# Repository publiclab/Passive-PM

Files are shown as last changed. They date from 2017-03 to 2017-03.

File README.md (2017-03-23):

## Introduction to the Passive PM Monitor
A [passive PM monitor](https://publiclab.org/wiki/passive-pm) collects airborne particles deposited on its surface without the use of mechanical or electrical systems. 

This passive PM monitor collects particulate matter on a glass slide cover. The slide cover is then [imaged with a microscope](microscopy/README.md), each particle is measured, and an [analysis protocol](analysis) is used to extrapolate the airborne concentration of coarse PM (PM<sub>2.5-10</sub>) during the sample period. 

The Passive PM Monitor was developed at the University of Iowa based on the University of North Carolina Passive PM Monitor. Components developed at UNC are subject to US Patent 6,321,608 until April 7, 2020 and are not to be used unless under [license](license.md). Public Lab has an evaluation license from UNC for evaluating the use of the monitor for community science monitoring. [Contact Public Lab](staff@publiclab.org) about becoming an evaluation partner. 
 
## Components of the Passive PM Monitor

### Hardware
The core Passive PM Monitor hardware is an aluminum [SEM stub](SEM_stub) and machined aluminum cap and screen, underneath which sits a microscope slide cover. This component is subject to patent protection.

[image]

The SEM stub sits between a [housing](housing) consisting of two plates that protect the slide from inclement weather and also normalize the flow of air across the stub and enable the use of the Passive PM Monitor in outdoor environments.

[image]

### [Microscopy](microscopy)
Accurate measurements of PM<sub>2.5-10</sub> require that the slide surface where particles are deposited be imaged as completely as possible.  It is recommended to automate this process. We are using the [OpenFlexure]x(LINK) microscope for automated imaging.

Images must then be processed to isolate and measure each deposited particle. Processing is currently happening with ImageJ.  See more details in [Microscopy](microscopy)

[4-up image of processing]

### Analysis
Imaged and sized particles are entered into an analysis protocol that uses an atmospheric physics model to determine airborne concentration of coarse particulates (PM<sub>2.5-10</sub>) during the sample period.  This equation was developed at UNC and is subject to patent protections. 

### [how you can contribute](contributing.md)

### [Bibliography](Bibliography.md)

### About this project
The TALA repository is a project of [Public Lab](www.publiclab.org) to [collect ongoing research into kite anemometry](www.publiclab.org/tag/kite-anemometer) into a stable device replicating the TALA and licensed under [CERN OHL 1.2](LiCENSE.md).

To read more about using kite anemometers and find resources and sources used in this repository, visit the [Public Lab Wiki](publiclab.org/wiki/kite-anemometers). To learn more about contibuting, please read our [contribution guidelines](contributing.md).

>Manufacture, use, or sale of this device is protected by U.S. patent 6,321,608, owned by The University of North Carolina at Chapel Hill. Any party desiring a license to use the aforementioned patent for commercial purposes shall contact the Office of Commercialization & Economic Development at UNC at 919-966-3929.

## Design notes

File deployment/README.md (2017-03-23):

##Deploying Passive PM Monitors

https://publiclab.org/notes/mathew/10-26-2015/deploying-passive-particle-monitors

https://publiclab.org/notes/mathew/12-22-2015/passive-particle-monitor-deployments-feedback

_Materials needed_

* [Prepared](../preparation) [Passive PM Monitors](../monitor)
* [Monitor Housing](../housing)
* Tape tabs for covering the monitors (Arrow Flags, 3M)
* Two-axis Bubble Level
* [Deployment Worksheet](deployment.md)

Prepared passive PM monitors are packed in a stack of styrofoam cups, each one covered with a cup.  Each covering cup has a place to write the date and time of deployment. Inside each cup pair is a sampler covered with a tape tab to prevent dust from entering the clean stub in transit.

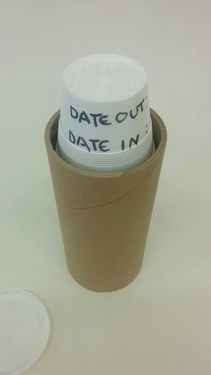
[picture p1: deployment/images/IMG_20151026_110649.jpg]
Boxed up samples


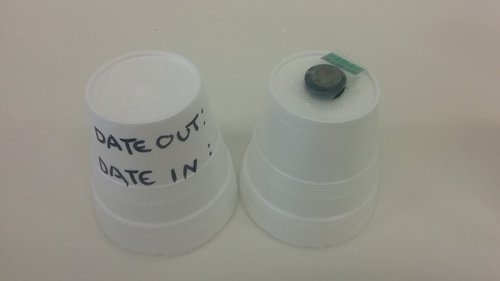
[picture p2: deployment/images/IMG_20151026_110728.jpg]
samples unstacked


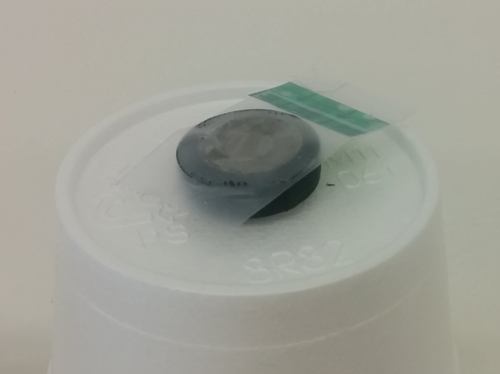
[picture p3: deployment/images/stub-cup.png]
stub close up


In order to analyze the results of a passive PM monitor deployment, each sample requires additional information, which should be recorded on separate Deployment Worksheet.

##Pick a Location for the housing

Ideally, monitors will be placed 180cm (71") above the ground, and a distance from obstacles greater than the height of those obstacles. Such an ideal deployment is not always possible. Describe and record the location and descriptions of obstacles in the Deployment Worksheet.  If possible, take photos of the deployment site. 

##One Week Deployment

Pick a day and time to deploy the passive PM monitor that you will also be available for in seven days to recover the monitor.  Record the date and time on the Deployment Worksheet.

1.
Clamp the passive PM monitor housing to a pole or other solid object.

2.
 Set the housing level using a bubble level, tightening the ball head's thumb screw.

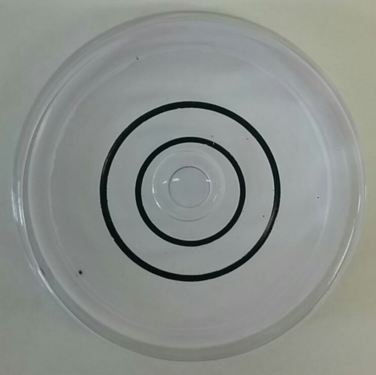
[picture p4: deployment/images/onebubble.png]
double bubble level
 
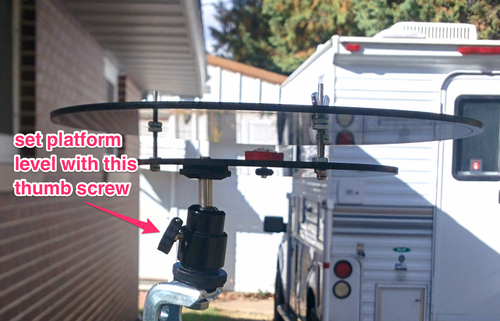
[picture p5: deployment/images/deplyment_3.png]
level the plates
 

3.
Remove sampler stub from box, leaving the tape tab cover on. write down the date and time it was removed on the cover cup.

4.
Unscrew the thumb screws holding the housing's lid on. watch for the rubber washers underneath, they're tiny and easy to lose (we provided some extras - you can use a dish as a catcher).

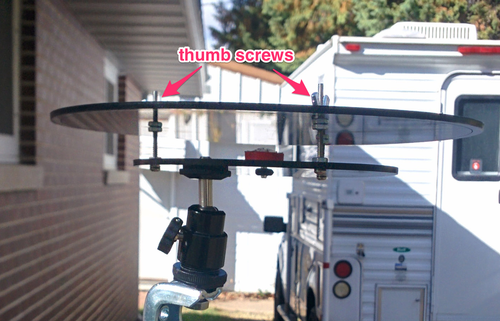
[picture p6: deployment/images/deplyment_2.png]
removing the housing lid


5.
Holding the sampler stub by its sides and supporting the housing with your other hand, press the sampler into the rubber grommet in the center of the housing. Try to avoid touching the top of the monitor, as in the center of the top there is a 1/4" area of fragile mesh that is easy to deform.

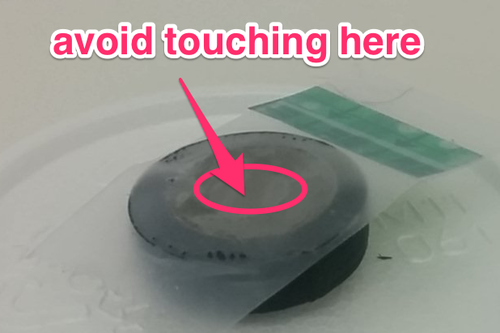
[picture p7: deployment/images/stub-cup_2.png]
Don't touch the fragile mesh


6.
Remove the sticky tab protecting the passive PM monitor and screw the housing's lid back on. The housing lid has a small groove on its underside that catches raindrops, make sure this groove is facing down.

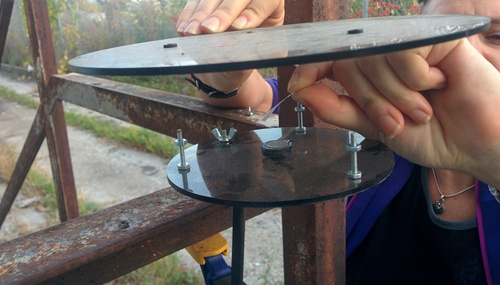
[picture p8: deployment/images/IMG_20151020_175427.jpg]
Re attach the housing's lid


7.
Use the bubble level to check if the housing is level. Reset the level of the housing using the thumb screw on the ball head if necessary.

level the plates

8.
Leave in place for seven days, and record daily weather information on the Deployment Worksheet. 

##Recovery

9.
Check the housing to see that it is still level.  Note any change in the Deployment Worksheet.

10.
Unscrew the housing lid and place a sticky tab over the sampler stub. Replace with a new sampler stub.

11.
Place the exposed sampler stub back in its box and write down the date and time it is returned on its cover cup.

12.
write the time of return on the Deployment Worksheet.

13.
Prepare samples for [microscopy](../microscopy) or package and ship to whomever is conducting the microscopy.

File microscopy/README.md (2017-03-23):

#PM Microscopy
The goal of PM microscopy is to use a visible light microscope and digital camera to capture and measure deposited particles so that their size, shape, and frequency can be [analyzed](../analysis). to extrapolate airborne PM during the sample period. 

The current microscopy hardware and software in use falls short in the face of several imaging issues and could use help. 

##Goals and Confounding Factors

The primary goal is to image and measure as much as possible of surface of the [passive PM monitor's](../monitor) deposition substrate- a glass slide cover- without taking repeat measurements. The greater the area imaged, the more accurate the [analysis](../analysis) gets.  250-300 particles are needed for "analytical certainty," and in the literature, imaging itself contributed 5% to the overall error.  (166, Ott et al. 2008)

The factors to be measured are:

* scale of microscope images in pixels/μm<sup>2</sup>
* area of each particle
 
* perimeter of each particle

From these measurements, additional factors are derived:

* total area imaged
* circularity of each particle (4π x Area/Perimeter<sup>2</sup>)

A microscopy protocol must account for false positives, mis-measurements and other issues arising from the qualities of the particles measured:

* refraction of light by particles
* varying albedo and opacity across each individual particle
* varying albedo and opacity of different types of particles

A microscopy protocol must also account for issues arising from imperfections in the microscope, related equipment, and imagine process including:

* dust and artifacts in the microscope's optics
* dust outside the focal plane
* pixel noise from the image sensor
* variable lighting within each image
* variable lighting between images
* variable lighting and exposure between image/sample sets
* duplicate images of the same particle

Solutions to these issues could be conducted in software or hardware-- a flatter, better focused light source could solve imaging variability, or a flat field or pseudo-flat field correction could solve the issue. 

##Current microscopy imaging protocol

The current protocol is based on manual microscopy using an OpenFlexure microscope.  As automated motor control for the [OpenFlexure](http://www.waterscope.org/3d-printing/) microscope advances, imaging will be [automated](https://github.com/fr293/motor_board).

####Materials
* deployed passive PM monitor
* standardized spheres 
 * Literature: 5μm borosilicate glass microspheres (was Duke Scientific 9005, now [Fisher Scientific 9005](https://www.thermofisher.com/order/catalog/product/CD9005)).
 * Currently using: PSL micropheres 2.07μm ([Ladd Research 40787](http://www.laddresearch.com/polystyrene-latex-spheres))
* stage micrometer ([Meiji Techno 285](http://meijitechno.com/ma285-1mm-divided-into-100-units))
* microscope with digital camera
 * Currently using an [OpenFlexure microscope LS65]((http://www.waterscope.org/3d-printing/))
 * 40x RML Objective, conjugate distance 160mm, DIN 45mm ([Nanjing City Srate](https://www.aliexpress.com/store/product/40X-0-65-DIN45mm-Achromatic-Objective-Lens-for-Biological-Microscope-195mm-Universal-Objectives/101130_32788001931.html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))

* Computer with [ImageJ](http://fiji.sc) and a particle measurement script from this repository

__Installing scripts in ImageJ__

##Microscope Calibration

Two different calibration targets are used for coarse and fine calibration of the microscope:: a stage micrometer and standardized spheres. Before calibration, adjustments will be made to the microscope and camera to achieve flat illumination across the image.

####achieving flat illumination
this is a stub. 

####Setting a rough calibration with a stage micrometer

Take an image with a stage micrometer.

![stage micrometer image]

Bring the image into ImageJ and use the line tool to draw a line between two points of the stage micrometer.

ImageJ Menu bar

![line drawn on stage micrometer in ImageJ]

Now go to the menu _Analyze > Set Scale_.

* Set unit length to μm
* check "global" (this will make it apply to all the other images opened)
* record the number of pixels/ μm

####Refining calibration with standardized spheres
We will now compare the stage micrometer calibration against standardized spheres in order to refine the pixels/μm calibration. The goal is to replicably measure the spheres within <sup>+/-</sup>5% of their known size.

Prep cover slip and slide according to [preparation guidelines](../preparation).

Use a permanent parker to add a focusing dot to the cover slip. 

![image])

Apply standardized spheres to the cover slip.

![image]

Take an image with the microscope with no sample in place.  This will be used for flatfield correction, and to account for dust in the optics. 

[Process image]
[Example image]

Place image with standardized spheres on the microscope.  Focus on the focusing dot, and take 3 to 5 images of the spheres.

Bring these images into ImageJ and apply the particle measurement script. 

[example image]

Save the CSV file produced by ImageJ and use a spreadsheet program to take an average particle measurement of the analyzed particles.

Repeat for each of the images taken.  Use the deviation from the spheres' known measurements to adjust the pixel/μm ratio in _Analyze > Set Scale_. 

Repeat the particle measurement to determine if particle measurements are within the appropriate range of <sup>+/-</sup>5%.

##Current Microscopy Imaging process

Samples can be scanned manually with the OpenFlexure microscope using the [Scan Pattern](scan_pattern.md). The scan pattern is drawn to-scale in scanplan4.dxf. It moves right to left,  taking 129 images covering 21% of the deposition surface area. 

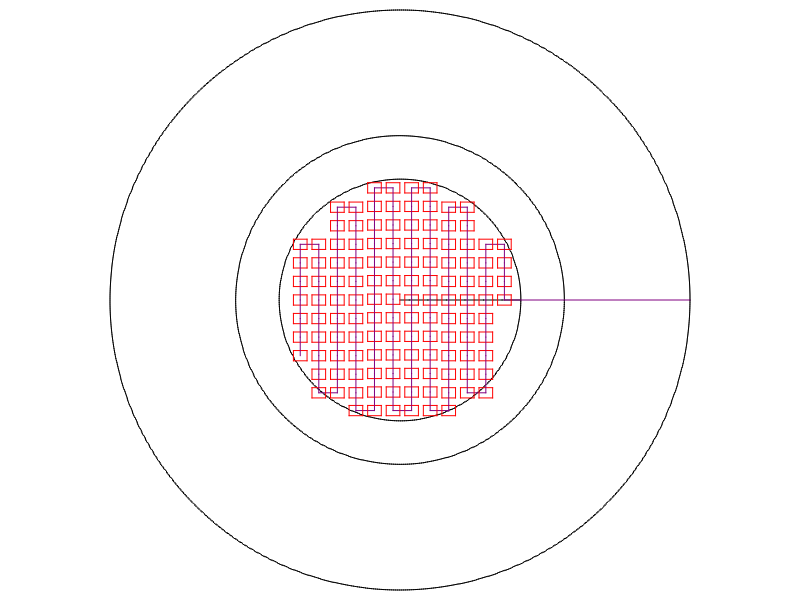
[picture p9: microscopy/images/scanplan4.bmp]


##Microscopy Measurement process

The steps below are implemented in a batch processing script in this repository folder. Load that script

INSTRUCTIONS

####Thresholding the image
Thresholding makes everything on one side of a color or lightness threshold a single color.  We are going to do it on a greyscale image to get a black and white image that is "binary," i.e. every pixel is either black or white.

First, convert the image to greyscale by going to _Image > Type > 8 bit_

Now we want to threshold the image to a binary image.  Go to _Image > Adjust > Threshold_

There are a variety of available modes, all of them seem to produce a decent binary image if the brightness is adjusted correctly.  It is an open question as to which we should use.

(https://i.publiclab.org/system/images/photos/000/011/638/original/Screen_Shot_2015-09-18_at_6.28.37_PM.png)

select a threshold that isolates particles without including noise.  This should be the same threshold used universally during processing, so some testing is called for. 

Now to make sure there aren't any greyscale elements left by using the command _Process > Binary > Make Binary_

You should have something like this:

(https://i.publiclab.org/system/images/photos/000/011/639/original/20xfrac_snd17-threshholded.png)

####Filling "Holes"

While thresholding gave us a good high-contrast image, somewhat transparent or reflective particles have "holes" inside them (left) that we want to fill (right):

(https://i.publiclab.org/system/images/photos/000/011/640/original/Screen_Shot_2015-09-18_at_6.32.18_PM.png)

Go to _Process > Binary > Fill Holes_

####Measurement
Now our image is ready to analyze.  We first need to set the measurements that will be taken. Go to _Analyze > Set Measurements_ and check off:

* Area
* Perimeter
* Shape Descriptors

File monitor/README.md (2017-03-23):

##U. Iowa-modified UNC Passive Monitor

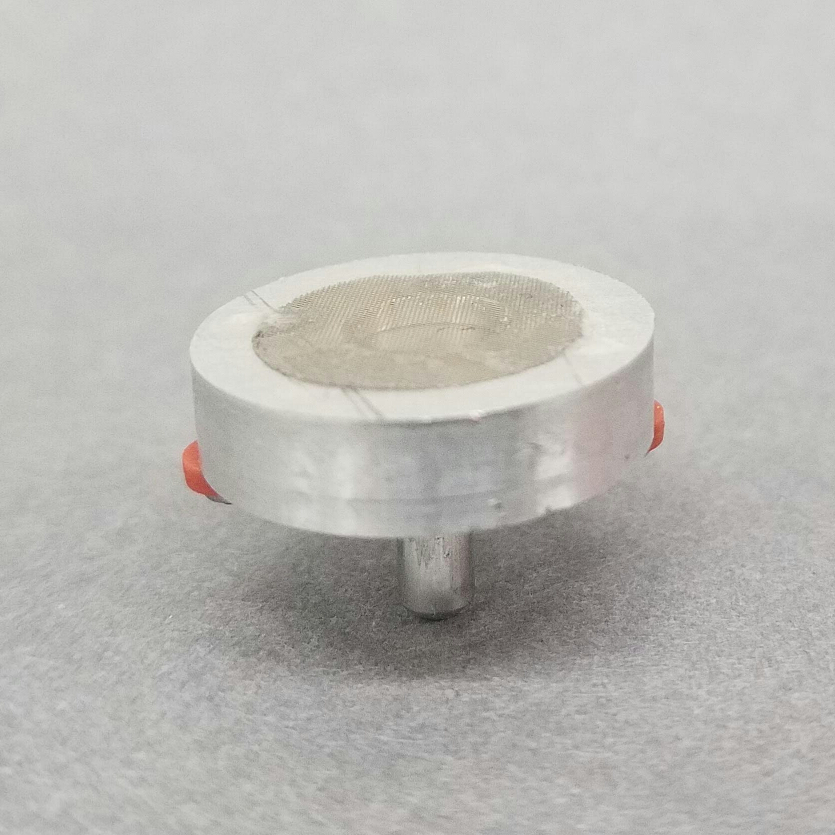
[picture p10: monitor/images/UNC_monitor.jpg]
U-Iowa/UNC passive monitor


The UNC Passive Monitor was originally developed for indoor PM monitoring and analysis with a Scanning Electron Microscope (SEM).  This device was modified by the University of Iowa to use visual light microscopy, as described in [Ott & Peters 2008](../bibliography.md).  A [housing](../housing) for the passive PM monitor was also developed to enable outdoor use.

Read more about identifying these parts in [this note on Publiclab.org.](https://publiclab.org/notes/mathew/09-02-2015/replicating-a-passive-dust-monitor-method)

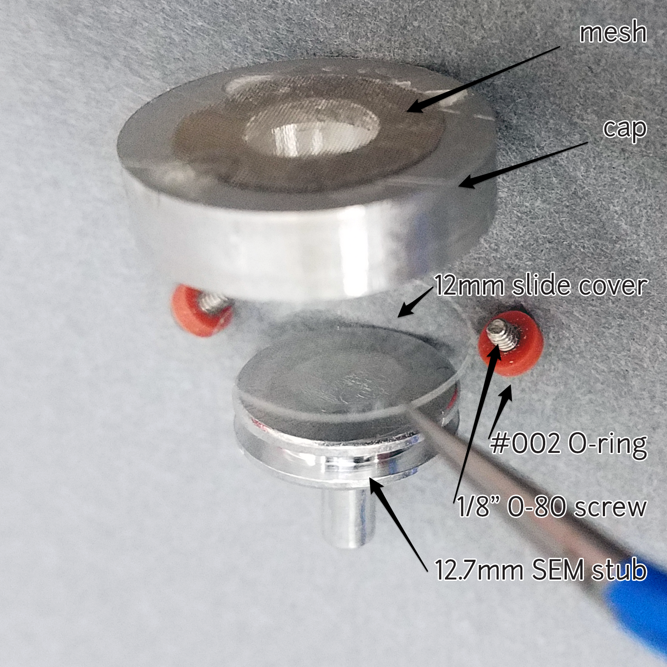
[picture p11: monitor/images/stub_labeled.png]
exploded image of SEM Stub Monitor


###components:

#####SEM stub
A standard SEM pin stub 12.7mm in diameter with an 8mm pin. [Ted Pella Part #16111](http://www.tedpella.com/SEM_html/SEMpinmount.htm)

#####Slide cover
12mm dia .015-.17mm thick circular cover glass for slides. [Fisher Scientific part #12-545-80](https://www.fishersci.com/shop/products/fisherbrand-cover-glasses-circles-11/1254580)

#####Screws
two  1/8” 0-80 stainless steel screws hold the SEM stub in place with size 002 square-profile silicone O-rings (3/64"ID, 9/64"OD). McMaster-Carr parts [#91772A052](https://www.mcmaster.com/#standard-rounded-head-screws/=15s9ecf) and [#1182N002](https://www.mcmaster.com/#o-rings/=15s9eqh)

#####Cap
The cap is specified to have the following dimensions:

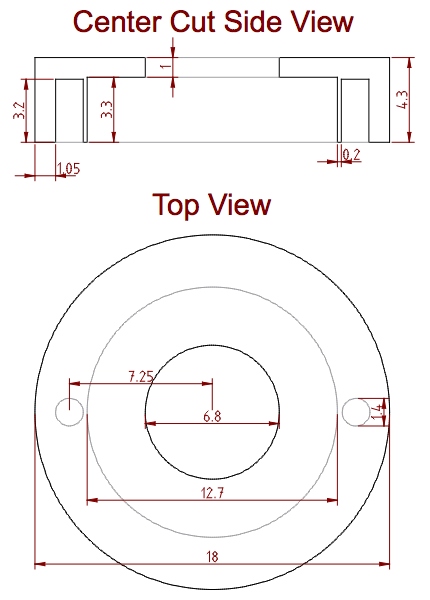
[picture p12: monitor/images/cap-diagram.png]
cap-diagram DXF


The original caps were milled from stainless steel, and a conductive material that does not build static charges is preferred. The caps in the project are made from 6061 aluminum, which as a soft metal is much easier to machine. 

Production files:
2D: [cap-diagram.dxf](cap-diagram.dxf), 3D:

#####Adhesive
Adhesive holds the mesh onto the cap. The original adhesive is unknown.

Currently cyanoacrylate (superglue) is used because it is easily dissolved in acetone and non-damaging to the mesh and cap.

#####mesh

1/2" (12.52mm) diameter 127μm thick nickel mesh is atop the cap.

The literature describes mesh sourced from Buckbee-Mears Inc. of St. Paul, having holes of conical cross section and dimensions of 160μm (top diameter) and 225μm (bottom diameter), a thickness of 127μm, a hole spacing of 280μm center-to-center, and 27% open area.

The current mesh in use is Precision EForming #75HH-160 electroformed nickel mesh, which does not conform to these dimensions (see below).

The mesh is best cut with a punch. A 1/2" punch such as this Osborne No. 245 belt punch ([item #51496](http://www.csosborneleathertools.com/product_detail.php?p_id=378)) and a wood or plastic mallet are preferred.

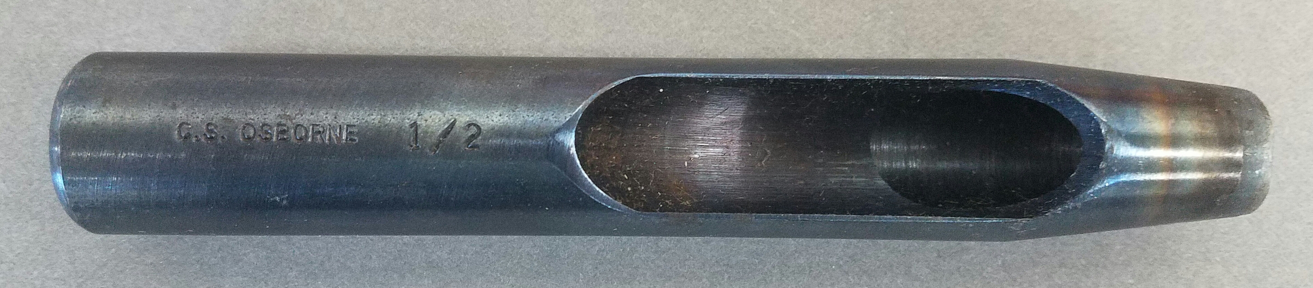
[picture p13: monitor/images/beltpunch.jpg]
Osborne No. 245 Belt Punch


Buckbee-Mears was absorbed into Precision Eforming of Cortland, NY, who, while claiming to produce a similar product, do not.  Precision EForming mesh #75HH-160 has symmetrical holes 160μm in diameter at their narrowest, approximately 200μm in diameter in the top and bottom of the hole, and with an open area of approximately 52%.

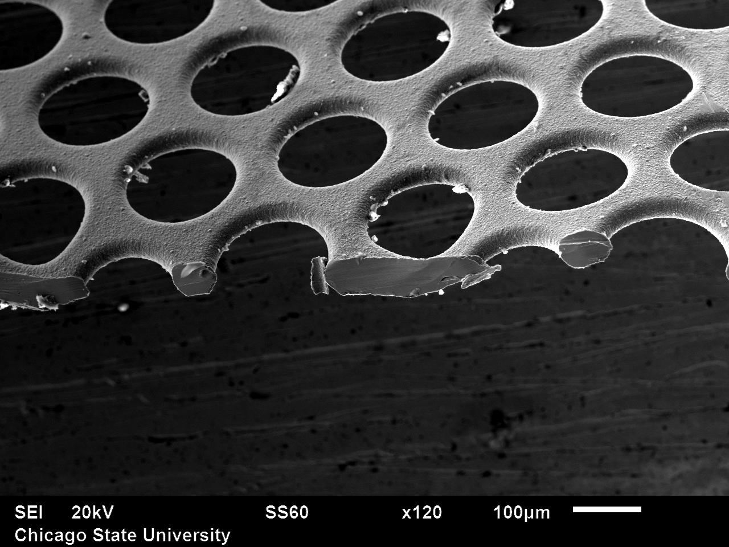
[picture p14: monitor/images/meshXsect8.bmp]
mesh cross section


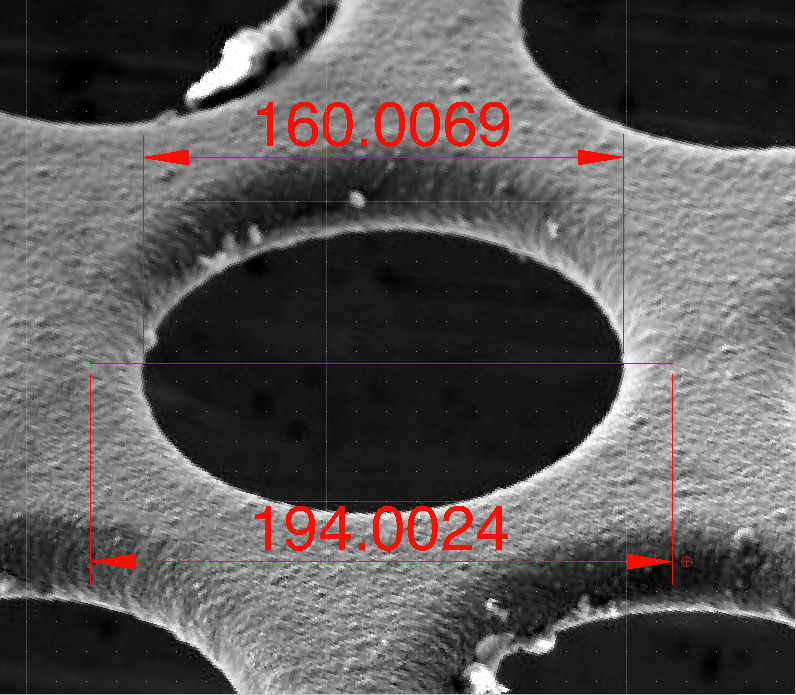
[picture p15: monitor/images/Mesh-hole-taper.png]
mesh hole taper


The Precision Eforming product is outside the preferred specification defined in Figures 1 & 2 of patent 6321608:

* hole diameter: 75μm to 610μm.
* thickness: 50μm to 200μm
* open area: 20-38%

>Manufacture, use, or sale of this device is protected by U.S. patent 6,321,608, owned by The University of North Carolina at Chapel Hill. Any party desiring a license to use the aforementioned patent for commercial purposes shall contact the Office of Commercialization & Economic Development at UNC at 919-966-3929.

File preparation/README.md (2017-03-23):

##Passive PM Monitor Preparation

Preparing [passive PM monitors](../Monitor) for [deployment](../deployment) requires inspecting, cleaning, covering, and packaging the monitors.

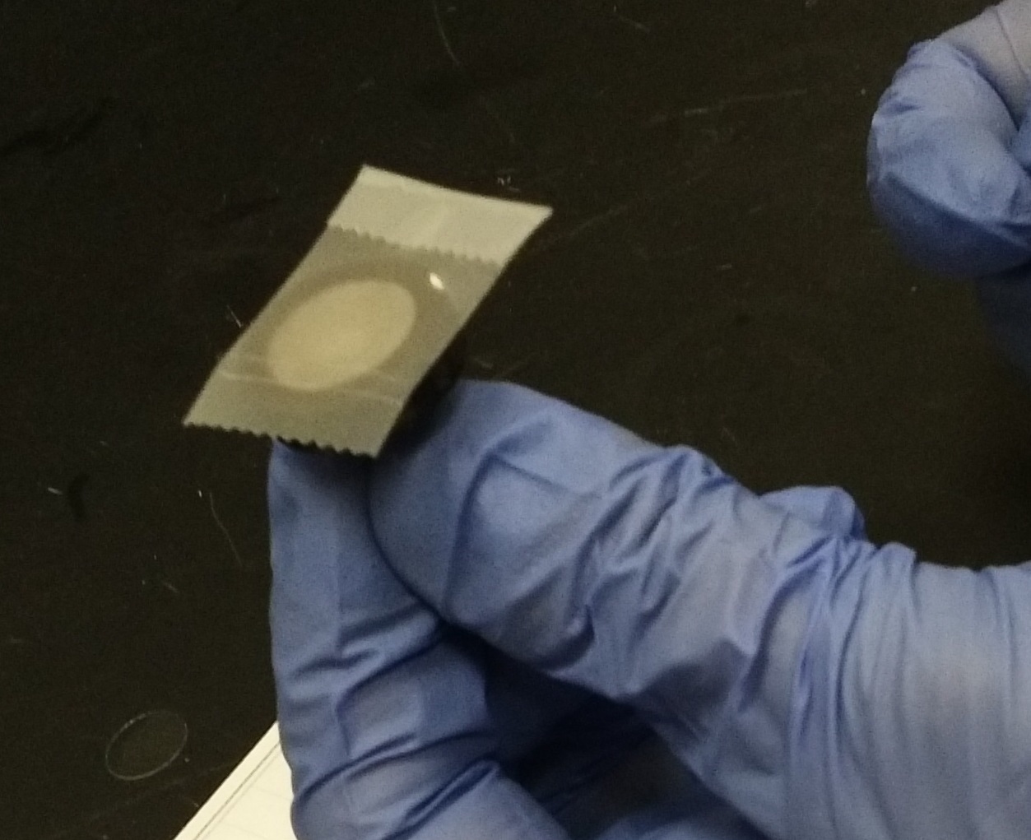
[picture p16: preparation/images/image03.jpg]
a cleaned and covered passive PM monitor


####Materials Needed
* [Passive PM Monitor](../Monitor)
* Powder-free disposable gloves (nitrile or similar)
* compressed air or 
* anti-static laboratory wipes such as KimWipes (#34155, Kimberly Clark)
* Anti-static strip (Staticmaster Polonium-210 Ionizer #1U200, Amstat Industries)
* Tape tabs for covering the monitors (Arrow Flags, 3M)
* polystyrene foam cups or SEM stub holder (Ted Pella 16709).
* fine-point permanent marker (Sharpie)

1. 
The mesh cap and SEM mount should be inspected for dust and grime and cleaned with compressed air*. 

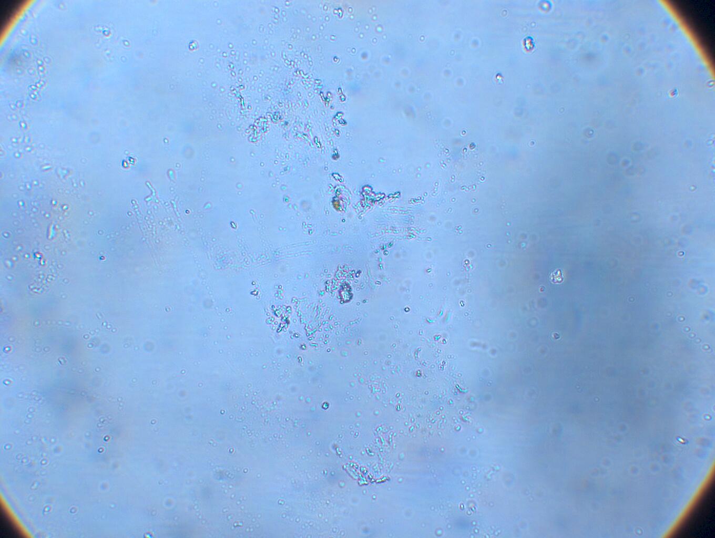
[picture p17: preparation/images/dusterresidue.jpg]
residue from aerosol electronics duster
>use real compressed air only, or an electric electronics duster. Aerosol can electronics dusters leave residue: 

2.
Clean the cover slip with a folded-over lab wipe, and inspect under a microscope to make sure it is free from shards of glass (pictured below) and generally clean. 

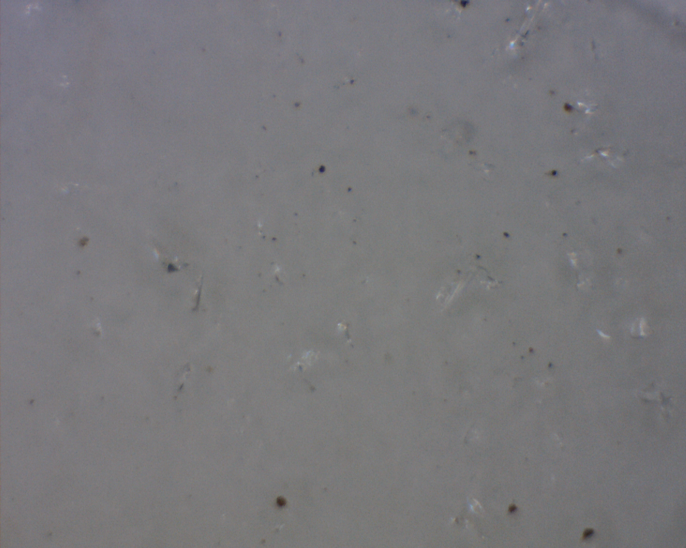
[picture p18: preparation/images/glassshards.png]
Glass shards on a cover slip


Coverslips may be cleaned with alcohol if necessary, and then cleaned with a lab wipe.

3.
Hold the cover slip within 1cm of the Anti-static strip to neutralize static charge.

4.
Use a permanent marker to mark a focusing dot on the edge of the cover slip.

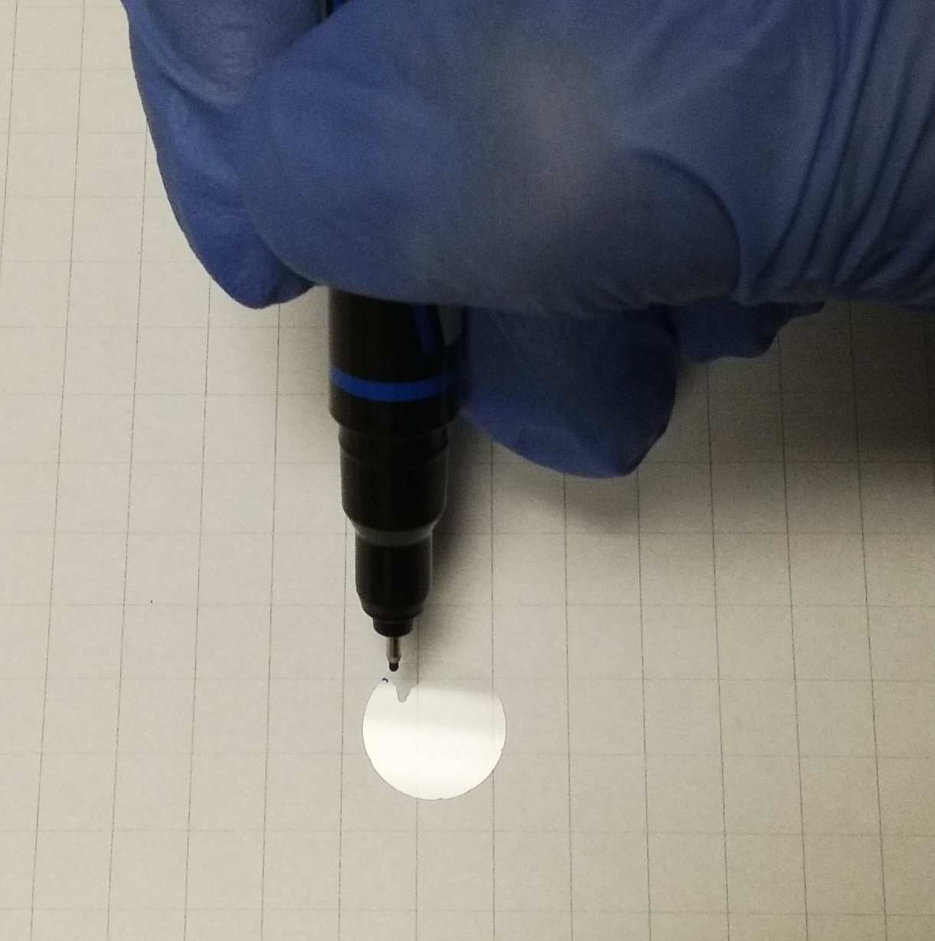
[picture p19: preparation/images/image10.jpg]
placing a focusing dot


5.
Place cover slip into the monitor's mesh cap, with the focusing dot facing the mesh.

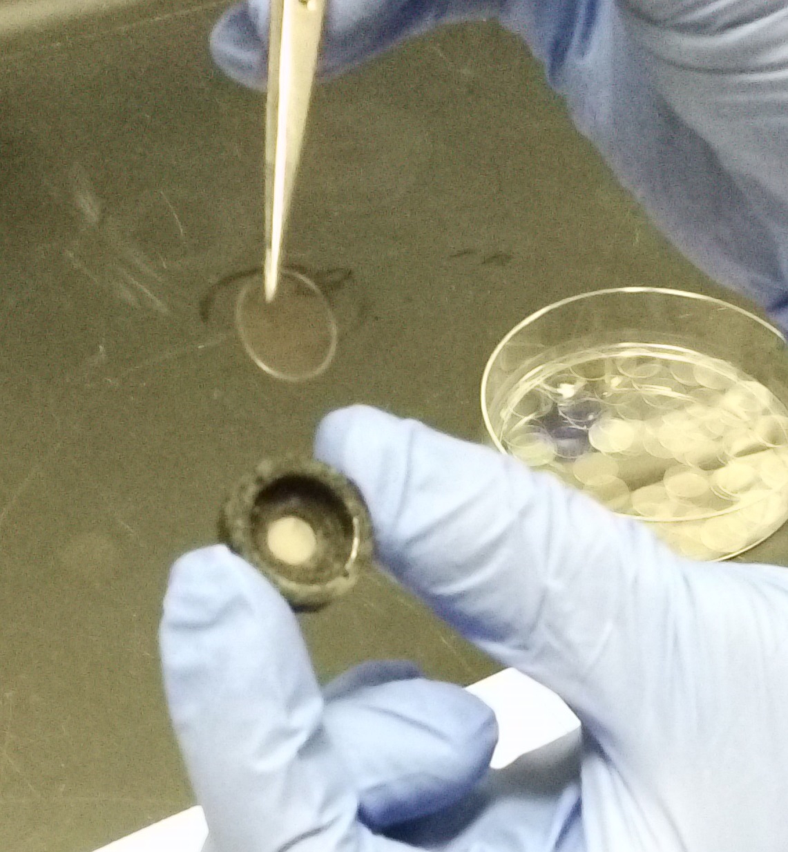
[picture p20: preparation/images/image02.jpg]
place cover slip in the mesh cap


6.
Use a permanent marker to draw a circle around the sampling area. 

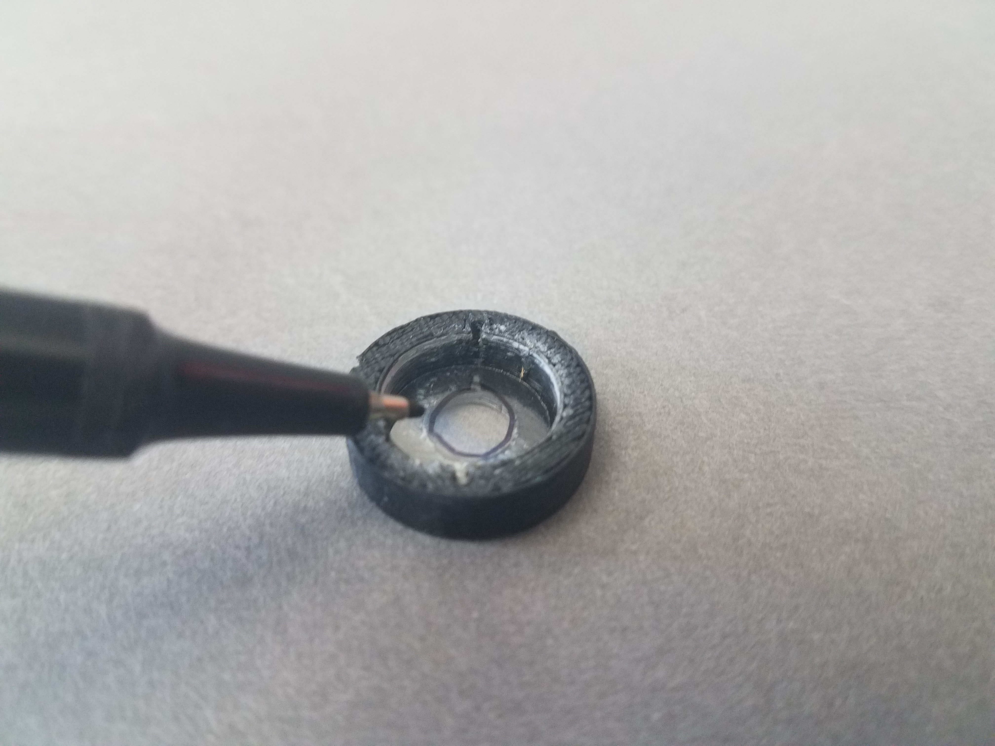
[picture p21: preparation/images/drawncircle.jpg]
draw a circle around the sampling area witha permanent marker

 
7.
Place the SEM stub into the cap and tighten in place with screws. 

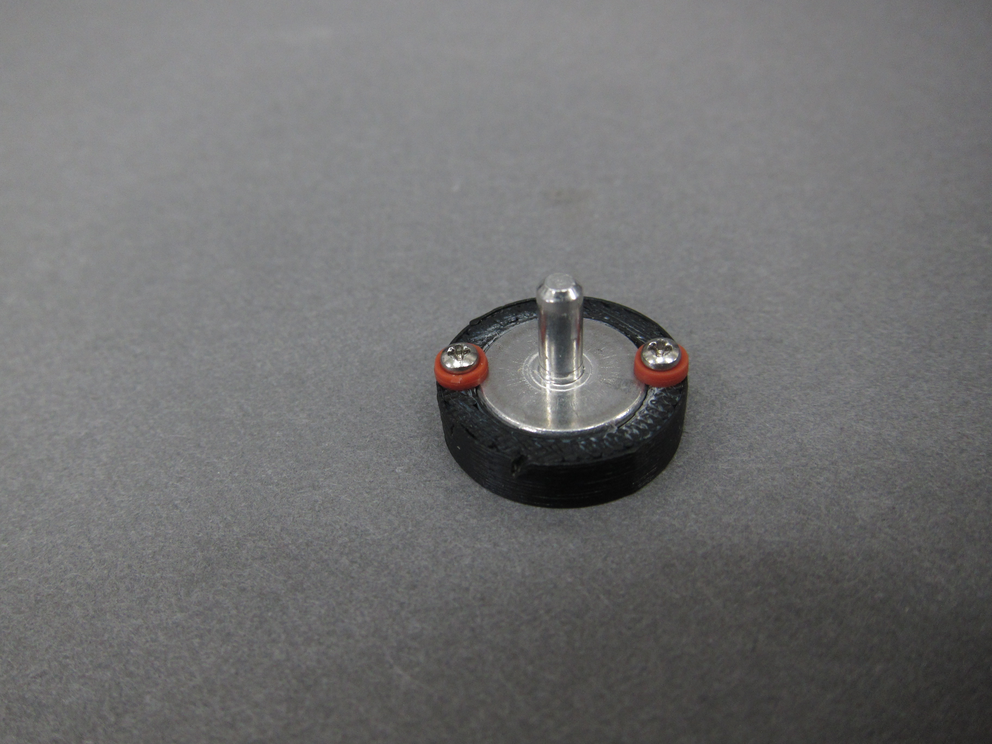
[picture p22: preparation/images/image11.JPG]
screws in place


8.
Place a tape tab over the mesh cover and push the stub of the monitor into the top of a polystyrene foam cup. (or alternatively, into an SEM stub holder)  Mark a covering cup or the holder with spaces indicating the time and location of sampling.

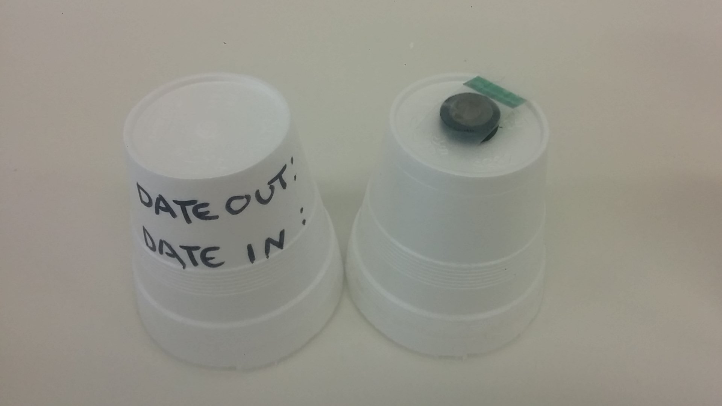
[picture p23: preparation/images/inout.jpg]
cups labeled


9.
[Deploy.](../deployment)

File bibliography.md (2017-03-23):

## Bibliography

#####Passive PM Monitor

2. Wagner, Jeff. Passive Aerosol Sampling. PhD Thesis. UNC Chapel Hill (2000).

3. Jeff Wagner and David Leith. Field tests of a passive aerosol sampler Aerosol Science 32  33-48 (2001)

4. Jeff Wagner and David Leith. Passive Aerosol Sampler. Part I: Principle of Operation. Aerosol Science and Technology 34: 186– 192 (2001)

5. Jeff Wagner and David Leith. Passive Aerosol Sampler. Part II: Wind Tunnel Experiments. Aerosol Science and Technology 34: 193– 201 (2001)

6. [Jeff Wagner and Janet M. Macher. Comparison of a Passive Aerosol Sampler to Size-Selective Pump Samplers in Indoor Environments. AIHA Journal 64 630–639 (2003)](//www.unc.edu/courses/2006spring/envr/116l/001/AIHAJ%2064%20630-639%20%282003%29%20Wagner%20and%20Macher.pdf)

7. [Darrin K. Ott & Thomas M. Peters. A Shelter to Protect a Passive Sampler for Coarse Particulate Matter, PM10 - 2.5. Aerosol Science and Technology 42:4, 299-309 (2008)](//www.tandfonline.com/doi/pdf/10.1080/02786820802054236)

8. Darrin K. Ott, William Cyrs, Thomas M. Peters. Passive measurement of coarse particulate matter, PM10-2.5. Aerosol Science 39 156 – 167 (2008)

9. Darrin K. Ott, Naresh Kumar, Thomas M. Peters. Passive sampling to capture spatial variability in PM10–2.5. Atmospheric Environment 42  746–756 (2008)

10. [R Willis, G Norris, T Watkins, E Sawvel, D Boysen, N Kumar, T Peters, G Casuccio. Characterization of Coarse PM Using Passive Samplers. National Ambient Air Monitoring Conference (2009)](//www.epa.gov/ttnamti1/files/2009conference/Watkins.pdf#page=2&zoom=auto,41,20)

11. David Nash and David Leith. Ultrafine Particle Sampling with the UNC Passive Aerosol Sampler. Aerosol Science and Technology, 44:12 1059-1064 (2010)

12. M Assael, D Melas, K Kakosimos. Monitoring Particulate Matter Concentrations with Passive Samplers: Application to the Greater Thesaloniki Area. Water, Air, and Soil Pollution, September (2010) 

13. Jeff Wagner, Kinnery Naik-Patel, Stephen Wall, Martha Harnly. Measurement of ambient particulate matter concentrations and particle types near agricultural burns using electron microscopy and passive samplers. Atmospheric Environment 54 260-271 (2012)

14. Peters, Grassian et al. Single-Particle SEM-EDX Analysis of Iron-Containing Coarse Particulate Matter in an Urban Environment: Sources and Distribution of Iron within Cleveland, Ohio. Environmental Science and Technology 46 4331−4339 (2012)

15. J Wagner, S Wall, K Naik-Patel, M Harnly. Measurement of ambient particulate matter concentrations and particle types near agricultural burns using electron microscopy and passive samplers. Atmospheric Environment 54 260-271 (2012)

16. Maiko Arashiro and David Leith. Precision of PM measurements with the UNC passive aerosol sampler. Journal of Aerosol Science 57 181–184 (2013)

17. Sawvel, Eric J. Use of passive samplers to characterize the spacial heterogeneity of course particle mass concentration and composition in Cleveland, OH. Thesis, University of Iowa (2013).

18. Jeff Wagner and Gary Casuccio. Spectral imaging and passive sampling to investigate particle sources in urban desert regions.  Environmental Science: Processes & Impacts 16 1745 (2014)

#####Atmospheric Physics background referenced in Passive PM literature

Hinds, William C. Aerosol Technology: Properties, Behavior, and Measurement of Airborne Particles. Chapter 11: Respiratory Deposition. New York: Wiley-Interscience Publications (1999)

#####[Other Passive PM Monitors](https://publiclab.org/wiki/passive-pm)

 R Brown, M Hemingway, D Wake, and J Thompson. Field Trials of an Electret-Based Passive Dust Sampler in Metal Processing Industries, Annals of Occupational Hygiene 39:603– 622 (1995)

Vinzents, PS. A Passive Personal Dust Monitor. Annals of Occupational Hygiene, 40: 261-80 (1996)

Schneider et al. Passive Sampler Used for Simultaneous Measurement of Breathing Zone Size Distribution, Inhalable Dust Concentration and other Size Fractions Involving Large Particles. Annals of Occupational Hygiene, 46:187-195 (2002)

Yamamoto et al. A passive sampler for airborne coarse particles Journal of Aerosol Science Volume 37, Issue 11, 1442–1454 (2006)

Fern, Martin. Development and Test of a Passive Sampler for Fine Particles. Swedish Environmental Research Institute (2010)
 
Einstein et al. Design and Validation of a Passive Deposition Sampler. Journal of Environonmental Monitoring 14(9), 2411–2420 (2012)

#####Total Suspended Particle  (TSP) [Sticky Pads](https://publiclab.org/notes/mathew/06-05-2014/the-development-of-stickypad-monitoring)

A. L. Beaman and R. W. S. M. Kingsbury. Assessment of Nuisance from Deposited Particles Using a Simple and Inexpensive Measuring System. Clean Air 11 (1981)

A. L. Beaman and R. W. S. M. Kingsbury. "Recent Developments in the Method of using Sticky Pads for the Measurement of Particulate Nuisance", Clean Air, 14(2), 74 - 81 (1984)

R.A. Farnfield W.J. Birch. Environmental Dust Monitoring Using Computer Scanned Images Obtained from Sticky Pad Poly-directional Dust Gauges. Clean Air 27 73-76 (1997)

H. Datson and W.J. Birch. The development of a novel method of directional dust monitoring. Environmental Monitoring & Assessment 124, 301-308 (2007)

Datson, Hall, and Birch. Validation of a New Method of Directional Air Monitoring. Atmospheric Environment 50 1e8 (2012)

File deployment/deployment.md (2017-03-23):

#Passive PM Monitor Deployment Worksheet

__Name:__

__Location Name:__

__Date & Time Deployed:__

__Date & Time Recovered:__

####Location Description 
_If this is a repeat deployment at a known location described on a previous Deployment Worksheet, you may skip this step._ 

If you have a camera, please photograph the location of your deployment, and a 360° view of the conditions around the deployment.

__Describe the location where the Passive PM Monitor is mounted:__ _(is it on a fence? A shed?)_
>.

>.

>.

>.

>.

__Please describe nearby obstacles__ _(house, office building, tree, etc.)_, __the distance to those obstacles, and an estimate of their heights.__ 

>.

>.

>.

>.

>.

>.

####Weather
Temperature and pressure effect the rate at which particulate matter deposits onto the passive PM monitor, while other events such as high winds and precipitation can also have major effects. Please record each day's temperature and pressure from the same source. We recommend using Weather Underground ([weatherunderground.com](https://weatherunderground.com)) to find the closest weather station to you.

__Weather source:__

Date|Temperature (°F)|Pressure (inches Hg)|Precipitation|Wind Speed|Wind Direction
------|------|-------|-----|-----|---
 |||||.
 |||||.
 |||||.
 |||||.
 |||||.
 |||||.
 |||||.

__Average Temperature:__

__Average Pressure:__

__Deployment notes:__
_Did the housing stay level? Did you notice emissions or other events that concerned you? anything else to note?_

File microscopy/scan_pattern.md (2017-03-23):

This scan pattern takes a series of images with no overlap across a 5mm circular area at the center of the 6.8mm deposition surface. The scan pattern assumes the use of a 20x zoom using a 60mm RMS objective on the OpenFlexure microscope LS65. Images taken with this objective are 282 x 212μm.

The total deposition area of the slide is 36317000μm<sup>2</sup>.  This procedure produces 127 images with an area of 7592500 or less, accounting for vingetting, or approximately 21% of the deposition area.

Each procedure step is described verbally and graphically.  All vertical traces are in increments of 1/2 turn, or 384μm (each tooth of the gear moves 32μm). Each ☐ box represents 1/2 turn and can be marked to indicate progress through the procedure.  All images to be taken are marked by the © copyright symbol, for ironic intent. Please release your images under open licenses or into the public domain.

After each vertical trace, a horizontal adjustment of 1/2 turn is taken. A ◁ is provided to mark horizontal adjustments. It points left to remind you [me] which way to go.  Arrows are also provided. You never can be too careful.

-------

(1) Find the right most edge. Move leftwards 3840um (5 full turns).

⬅︎ ☐ ☐ ☐ ☐ ☐ ☐ ☐ ☐ ☐ ☐

(2) take 4 images in a vertical trace, moving up 1/2 turn between each image, for a total of 1 1/2 turns. move left 1/2 turn.

⬆︎ © ☐ © ☐ © ☐ ©

⬅︎ ◁

(3) take 9 images in a vertical trace, moving down 1/2 turn between each for 4 full turns. move left 1/2 turn.

⬇︎ © ☐ © ☐ © ☐ © ☐ © ☐ © ☐ © ☐ © ☐ ©

⬅︎ ◁

(4) take 11 images in a vertical trace, moving up 1/2 turn between each for 5 full turns. move left 1/2 turn.

⬆︎ © ☐ © ☐ © ☐ © ☐ © ☐ © ☐ © ☐ © ☐ © ☐ © ☐ ©

⬅︎ ◁

(5) take 12 images in a vertical trace, moving down 1/2 turn between each for 5 1/2 full turns. move left 1/2 turn.

⬇︎ © ☐ © ☐ © ☐ © ☐ © ☐ © ☐ © ☐ © ☐ © ☐ © ☐ © ☐ ©

⬅︎ ◁

(6) take 13 images in a vertical trace, moving up 1/2 turn between each for 12 full turns. move left 1/2 turn.

⬆︎ © ☐ © ☐ © ☐ © ☐ © ☐ © ☐ © ☐ © ☐ © ☐ © ☐ © ☐ © ☐ ©

⬅︎ ◁

(7) take 13 images in a vertical trace, moving down 1/2 turn between each for 12 full turns. move left 1/2 turn.

⬇︎ © ☐ © ☐ © ☐ © ☐ © ☐ © ☐ © ☐ © ☐ © ☐ © ☐ © ☐ © ☐ ©

⬅︎ ◁

(8) take 13 images in a vertical trace, moving up 1/2 turn between each for 12 full turns. move left 1/2 turn.

⬆︎ © ☐ © ☐ © ☐ © ☐ © ☐ © ☐ © ☐ © ☐ © ☐ © ☐ © ☐ © ☐ ©

⬅︎ ◁

(9) take 13 images in a vertical trace, moving down 1/2 turn between each for 12 full turns. move left 1/2 turn.

⬇︎ © ☐ © ☐ © ☐ © ☐ © ☐ © ☐ © ☐ © ☐ © ☐ © ☐ © ☐ © ☐ ©

⬅︎ ◁

(10) take 12 images in a vertical trace, moving up 1/2 turn between each for 5 1/2 full turns. move left 1/2 turn.

⬆︎ © ☐ © ☐ © ☐ © ☐ © ☐ © ☐ © ☐ © ☐ © ☐ © ☐ © ☐ ©

⬅︎ ◁

(11) take 11 images in a vertical trace, moving down 1/2 turn between each for 5 full turns. move left 1/2 turn.

⬇︎ © ☐ © ☐ © ☐ © ☐ © ☐ © ☐ © ☐ © ☐ © ☐ © ☐ © 

⬅︎ ◁

(12) take 9 images in a vertical trace, moving up 1/2 turn between each for 4 full turns. move left 1/2 turn.

⬆︎ © ☐ © ☐ © ☐ © ☐ © ☐ © ☐ © ☐ © ☐ ©

⬅︎ ◁

(13) take 7 images in a vertical trace, moving down 1/2 turn between each for 3 full turns. move left 1/2 turn.

⬇︎ © ☐ © ☐ © ☐ © ☐ © ☐ © ☐ ©

⬅︎ ◁

__Done!__

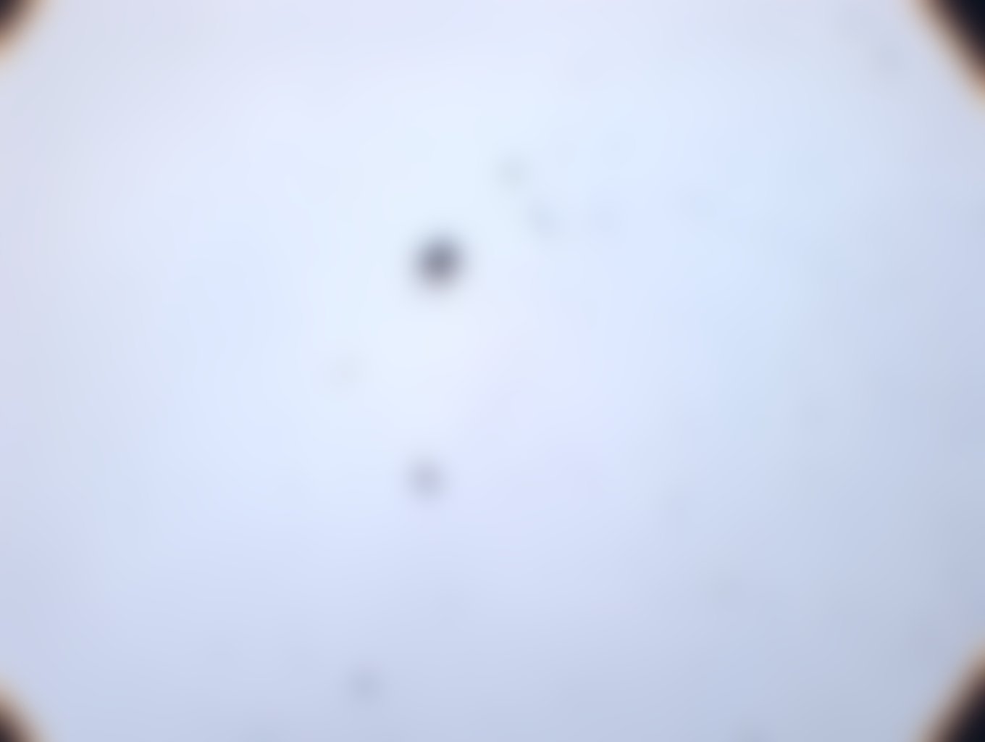
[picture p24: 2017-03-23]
microscopy/images/11_2_15_PG2_8_20x_blur.jpg

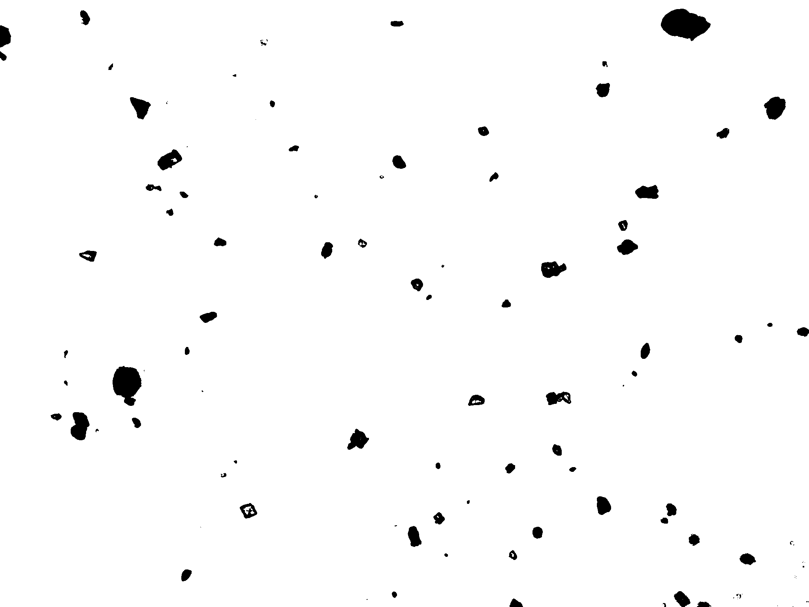
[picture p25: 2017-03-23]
microscopy/images/20xfrac_snd17-threshholded.png

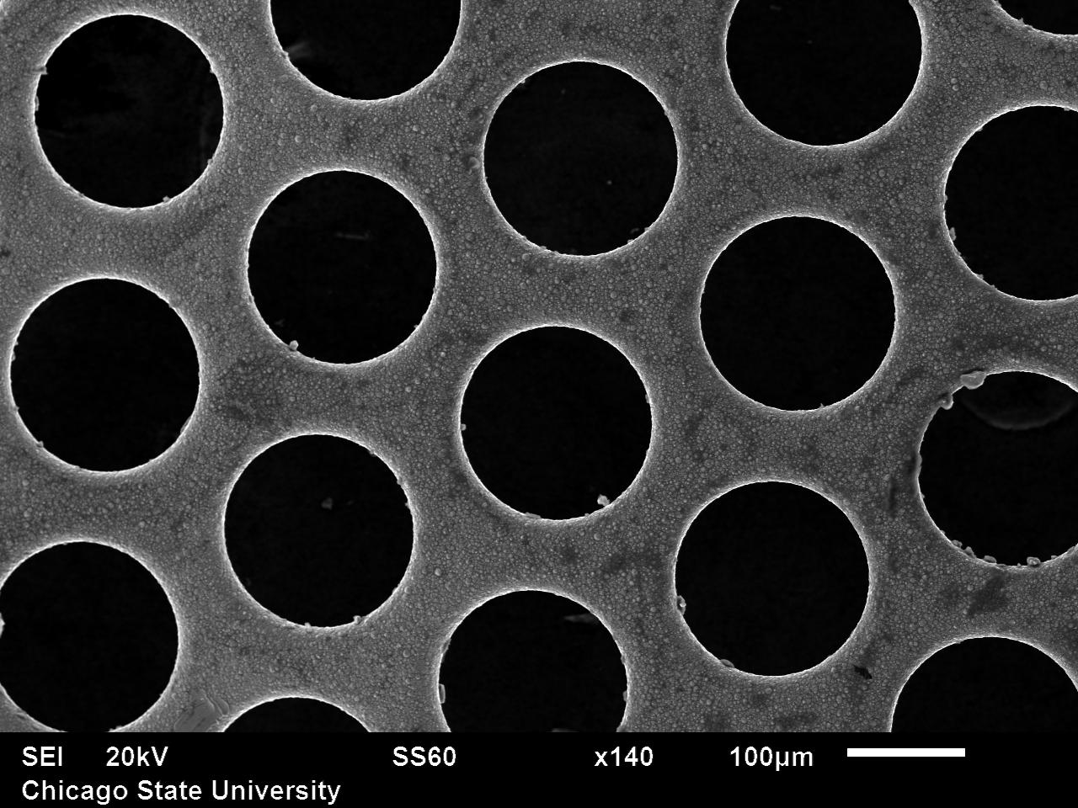
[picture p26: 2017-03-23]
monitor/images/mesh8.bmp

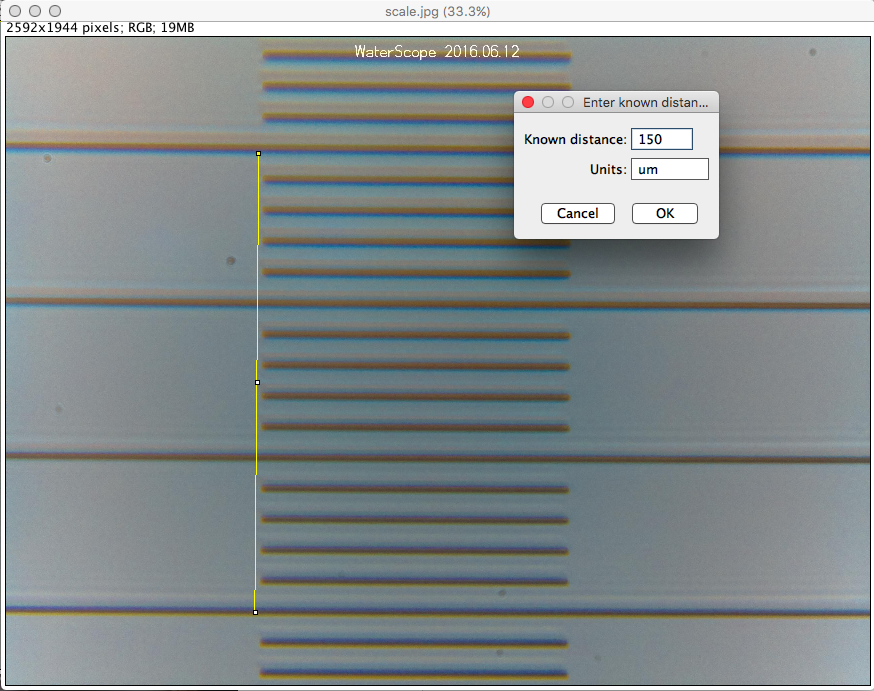
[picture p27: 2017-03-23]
microscopy/images/Screen Shot 2016-09-23 at 3.48.48 PM.png

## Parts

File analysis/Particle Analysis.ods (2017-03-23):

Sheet: sample metadata
Sample start (date) | 11/30/2015
Sample end (date) | 12/7/2015

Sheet: sample particle data
image name | particle number | Area | Perimeter | Circularity | projected-area Diameter (um) | particle mass (g) | mass Flux (g/um^2/s) | relaxation Time (s) | Ambient deposition (um/s) | mesh factor | deposition Value um/s | Ci contribution to mass concentration (g/um^3) | Ci (ug/m^3) | size fraction? | E individual PM10 | E individual PM2.5 | E individual big | C x E PM2.5 | C x E PM10 | C x E PM2.5-PM10
 |  |  |  |  |  |  |  |  |  |  |  |  |  |  |  |  |  | #DIV/0! | #DIV/0!
 |  |  |  |  | 0 | #DIV/0! | #DIV/0! | 0.00E+00 | 0.00E+00 | #NUM! | #NUM! | #DIV/0! | #DIV/0! |  | 0.9585 | 1.00E+00 |  | #DIV/0! | #DIV/0! | #DIV/0!
 |  |  |  |  | 0 | #DIV/0! | #DIV/0! | 0.00E+00 | 0.00E+00 | #NUM! | #NUM! | #DIV/0! | #DIV/0! |  | 0.9585 | 1.00E+00 |  | #DIV/0! | #DIV/0! | #DIV/0!
 |  |  |  |  | 0 | #DIV/0! | #DIV/0! | 0.00E+00 | 0.00E+00 | #NUM! | #NUM! | #DIV/0! | #DIV/0! |  | 0.9585 | 1.00E+00 |  | #DIV/0! | #DIV/0! | #DIV/0!
 |  |  |  |  | 0 | #DIV/0! | #DIV/0! | 0.00E+00 | 0.00E+00 | #NUM! | #NUM! | #DIV/0! | #DIV/0! |  | 0.9585 | 1.00E+00 |  | #DIV/0! | #DIV/0! | #DIV/0!
 |  |  |  |  | 0 | #DIV/0! | #DIV/0! | 0.00E+00 | 0.00E+00 | #NUM! | #NUM! | #DIV/0! | #DIV/0! |  | 0.9585 | 1.00E+00 |  | #DIV/0! | #DIV/0! | #DIV/0!
 |  |  |  |  | 0 | #DIV/0! | #DIV/0! | 0.00E+00 | 0.00E+00 | #NUM! | #NUM! | #DIV/0! | #DIV/0! |  | 0.9585 | 1.00E+00 |  | #DIV/0! | #DIV/0! | #DIV/0!
 |  |  |  |  | 0 | #DIV/0! | #DIV/0! | 0.00E+00 | 0.00E+00 | #NUM! | #NUM! | #DIV/0! | #DIV/0! |  | 0.9585 | 1.00E+00 |  | #DIV/0! | #DIV/0! | #DIV/0!
 |  |  |  |  | 0 | #DIV/0! | #DIV/0! | 0.00E+00 | 0.00E+00 | #NUM! | #NUM! | #DIV/0! | #DIV/0! |  | 0.9585 | 1.00E+00 |  | #DIV/0! | #DIV/0! | #DIV/0!
 |  |  |  |  | 0 | #DIV/0! | #DIV/0! | 0.00E+00 | 0.00E+00 | #NUM! | #NUM! | #DIV/0! | #DIV/0! |  | 0.9585 | 1.00E+00 |  | #DIV/0! | #DIV/0! | #DIV/0!
 |  |  |  |  | 0 | #DIV/0! | #DIV/0! | 0.00E+00 | 0.00E+00 | #NUM! | #NUM! | #DIV/0! | #DIV/0! |  | 0.9585 | 1.00E+00 |  | #DIV/0! | #DIV/0! | #DIV/0!
 |  |  |  |  | 0 | #DIV/0! | #DIV/0! | 0.00E+00 | 0.00E+00 | #NUM! | #NUM! | #DIV/0! | #DIV/0! |  | 0.9585 | 1.00E+00 |  | #DIV/0! | #DIV/0! | #DIV/0!
 |  |  |  |  | 0 | #DIV/0! | #DIV/0! | 0.00E+00 | 0.00E+00 | #NUM! | #NUM! | #DIV/0! | #DIV/0! |  | 0.9585 | 1.00E+00 |  | #DIV/0! | #DIV/0! | #DIV/0!
 |  |  |  |  | 0 | #DIV/0! | #DIV/0! | 0.00E+00 | 0.00E+00 | #NUM! | #NUM! | #DIV/0! | #DIV/0! |  | 0.9585 | 1.00E+00 |  | #DIV/0! | #DIV/0! | #DIV/0!
 |  |  |  |  | 0 | #DIV/0! | #DIV/0! | 0.00E+00 | 0.00E+00 | #NUM! | #NUM! | #DIV/0! | #DIV/0! |  | 0.9585 | 1.00E+00 |  | #DIV/0! | #DIV/0! | #DIV/0!
 |  |  |  |  | 0 | #DIV/0! | #DIV/0! | 0.00E+00 | 0.00E+00 | #NUM! | #NUM! | #DIV/0! | #DIV/0! |  | 0.9585 | 1.00E+00 |  | #DIV/0! | #DIV/0! | #DIV/0!
 |  |  |  |  | 0 | #DIV/0! | #DIV/0! | 0.00E+00 | 0.00E+00 | #NUM! | #NUM! | #DIV/0! | #DIV/0! |  | 0.9585 | 1.00E+00 |  | #DIV/0! | #DIV/0! | #DIV/0!
 |  |  |  |  | 0 | #DIV/0! | #DIV/0! | 0.00E+00 | 0.00E+00 | #NUM! | #NUM! | #DIV/0! | #DIV/0! |  | 0.9585 | 1.00E+00 |  | #DIV/0! | #DIV/0! | #DIV/0!
 |  |  |  |  | 0 | #DIV/0! | #DIV/0! | 0.00E+00 | 0.00E+00 | #NUM! | #NUM! | #DIV/0! | #DIV/0! |  | 0.9585 | 1.00E+00 |  | #DIV/0! | #DIV/0! | #DIV/0!
 |  |  |  |  | 0 | #DIV/0! | #DIV/0! | 0.00E+00 | 0.00E+00 | #NUM! | #NUM! | #DIV/0! | #DIV/0! |  | 0.9585 | 1.00E+00 |  | #DIV/0! | #DIV/0! | #DIV/0!
 |  |  |  |  | 0 | #DIV/0! | #DIV/0! | 0.00E+00 | 0.00E+00 | #NUM! | #NUM! | #DIV/0! | #DIV/0! |  | 0.9585 | 1.00E+00 |  | #DIV/0! | #DIV/0! | #DIV/0!
 |  |  |  |  | 0 | #DIV/0! | #DIV/0! | 0.00E+00 | 0.00E+00 | #NUM! | #NUM! | #DIV/0! | #DIV/0! |  | 0.9585 | 1.00E+00 |  | #DIV/0! | #DIV/0! | #DIV/0!
 |  |  |  |  | 0 | #DIV/0! | #DIV/0! | 0.00E+00 | 0.00E+00 | #NUM! | #NUM! | #DIV/0! | #DIV/0! |  | 0.9585 | 1.00E+00 |  | #DIV/0! | #DIV/0! | #DIV/0!
 |  |  |  |  | 0 | #DIV/0! | #DIV/0! | 0.00E+00 | 0.00E+00 | #NUM! | #NUM! | #DIV/0! | #DIV/0! |  | 0.9585 | 1.00E+00 |  | #DIV/0! | #DIV/0! | #DIV/0!
 |  |  |  |  | 0 | #DIV/0! | #DIV/0! | 0.00E+00 | 0.00E+00 | #NUM! | #NUM! | #DIV/0! | #DIV/0! |  | 0.9585 | 1.00E+00 |  | #DIV/0! | #DIV/0! | #DIV/0!
 |  |  |  |  | 0 | #DIV/0! | #DIV/0! | 0.00E+00 | 0.00E+00 | #NUM! | #NUM! | #DIV/0! | #DIV/0! |  | 0.9585 | 1.00E+00 |  | #DIV/0! | #DIV/0! | #DIV/0!
 |  |  |  |  | 0 | #DIV/0! | #DIV/0! | 0.00E+00 | 0.00E+00 | #NUM! | #NUM! | #DIV/0! | #DIV/0! |  | 0.9585 | 1.00E+00 |  | #DIV/0! | #DIV/0! | #DIV/0!
 |  |  |  |  | 0 | #DIV/0! | #DIV/0! | 0.00E+00 | 0.00E+00 | #NUM! | #NUM! | #DIV/0! | #DIV/0! |  | 0.9585 | 1.00E+00 |  | #DIV/0! | #DIV/0! | #DIV/0!
 |  |  |  |  | 0 | #DIV/0! | #DIV/0! | 0.00E+00 | 0.00E+00 | #NUM! | #NUM! | #DIV/0! | #DIV/0! |  | 0.9585 | 1.00E+00 |  | #DIV/0! | #DIV/0! | #DIV/0!
 |  |  |  |  | 0 | #DIV/0! | #DIV/0! | 0.00E+00 | 0.00E+00 | #NUM! | #NUM! | #DIV/0! | #DIV/0! |  | 0.9585 | 1.00E+00 |  | #DIV/0! | #DIV/0! | #DIV/0!
 |  |  |  |  | 0 | #DIV/0! | #DIV/0! | 0.00E+00 | 0.00E+00 | #NUM! | #NUM! | #DIV/0! | #DIV/0! |  | 0.9585 | 1.00E+00 |  | #DIV/0! | #DIV/0! | #DIV/0!
 |  |  |  |  | 0 | #DIV/0! | #DIV/0! | 0.00E+00 | 0.00E+00 | #NUM! | #NUM! | #DIV/0! | #DIV/0! |  | 0.9585 | 1.00E+00 |  | #DIV/0! | #DIV/0! | #DIV/0!
 |  |  |  |  | 0 | #DIV/0! | #DIV/0! | 0.00E+00 | 0.00E+00 | #NUM! | #NUM! | #DIV/0! | #DIV/0! |  | 0.9585 | 1.00E+00 |  | #DIV/0! | #DIV/0! | #DIV/0!
 |  |  |  |  | 0 | #DIV/0! | #DIV/0! | 0.00E+00 | 0.00E+00 | #NUM! | #NUM! | #DIV/0! | #DIV/0! |  | 0.9585 | 1.00E+00 |  | #DIV/0! | #DIV/0! | #DIV/0!
 |  |  |  |  | 0 | #DIV/0! | #DIV/0! | 0.00E+00 | 0.00E+00 | #NUM! | #NUM! | #DIV/0! | #DIV/0! |  | 0.9585 | 1.00E+00 |  | #DIV/0! | #DIV/0! | #DIV/0!
 |  |  |  |  | 0 | #DIV/0! | #DIV/0! | 0.00E+00 | 0.00E+00 | #NUM! | #NUM! | #DIV/0! | #DIV/0! |  | 0.9585 | 1.00E+00 |  | #DIV/0! | #DIV/0! | #DIV/0!
 |  |  |  |  | 0 | #DIV/0! | #DIV/0! | 0.00E+00 | 0.00E+00 | #NUM! | #NUM! | #DIV/0! | #DIV/0! |  | 0.9585 | 1.00E+00 |  | #DIV/0! | #DIV/0! | #DIV/0!
 |  |  |  |  | 0 | #DIV/0! | #DIV/0! | 0.00E+00 | 0.00E+00 | #NUM! | #NUM! | #DIV/0! | #DIV/0! |  | 0.9585 | 1.00E+00 |  | #DIV/0! | #DIV/0! | #DIV/0!
 |  |  |  |  | 0 | #DIV/0! | #DIV/0! | 0.00E+00 | 0.00E+00 | #NUM! | #NUM! | #DIV/0! | #DIV/0! |  | 0.9585 | 1.00E+00 |  | #DIV/0! | #DIV/0! | #DIV/0!
 |  |  |  |  | 0 | #DIV/0! | #DIV/0! | 0.00E+00 | 0.00E+00 | #NUM! | #NUM! | #DIV/0! | #DIV/0! |  | 0.9585 | 1.00E+00 |  | #DIV/0! | #DIV/0! | #DIV/0!
 |  |  |  |  | 0 | #DIV/0! | #DIV/0! | 0.00E+00 | 0.00E+00 | #NUM! | #NUM! | #DIV/0! | #DIV/0! |  | 0.9585 | 1.00E+00 |  | #DIV/0! | #DIV/0! | #DIV/0!
 |  |  |  |  | 0 | #DIV/0! | #DIV/0! | 0.00E+00 | 0.00E+00 | #NUM! | #NUM! | #DIV/0! | #DIV/0! |  | 0.9585 | 1.00E+00 |  | #DIV/0! | #DIV/0! | #DIV/0!
 |  |  |  |  | 0 | #DIV/0! | #DIV/0! | 0.00E+00 | 0.00E+00 | #NUM! | #NUM! | #DIV/0! | #DIV/0! |  | 0.9585 | 1.00E+00 |  | #DIV/0! | #DIV/0! | #DIV/0!
 |  |  |  |  | 0 | #DIV/0! | #DIV/0! | 0.00E+00 | 0.00E+00 | #NUM! | #NUM! | #DIV/0! | #DIV/0! |  | 0.9585 | 1.00E+00 |  | #DIV/0! | #DIV/0! | #DIV/0!
 |  |  |  |  | 0 | #DIV/0! | #DIV/0! | 0.00E+00 | 0.00E+00 | #NUM! | #NUM! | #DIV/0! | #DIV/0! |  | 0.9585 | 1.00E+00 |  | #DIV/0! | #DIV/0! | #DIV/0!
 |  |  |  |  | 0 | #DIV/0! | #DIV/0! | 0.00E+00 | 0.00E+00 | #NUM! | #NUM! | #DIV/0! | #DIV/0! |  | 0.9585 | 1.00E+00 |  | #DIV/0! | #DIV/0! | #DIV/0!
 |  |  |  |  | 0 | #DIV/0! | #DIV/0! | 0.00E+00 | 0.00E+00 | #NUM! | #NUM! | #DIV/0! | #DIV/0! |  | 0.9585 | 1.00E+00 |  | #DIV/0! | #DIV/0! | #DIV/0!
 |  |  |  |  | 0 | #DIV/0! | #DIV/0! | 0.00E+00 | 0.00E+00 | #NUM! | #NUM! | #DIV/0! | #DIV/0! |  | 0.9585 | 1.00E+00 |  | #DIV/0! | #DIV/0! | #DIV/0!
 |  |  |  |  | 0 | #DIV/0! | #DIV/0! | 0.00E+00 | 0.00E+00 | #NUM! | #NUM! | #DIV/0! | #DIV/0! |  | 0.9585 | 1.00E+00 |  | #DIV/0! | #DIV/0! | #DIV/0!
 |  |  |  |  | 0 | #DIV/0! | #DIV/0! | 0.00E+00 | 0.00E+00 | #NUM! | #NUM! | #DIV/0! | #DIV/0! |  | 0.9585 | 1.00E+00 |  | #DIV/0! | #DIV/0! | #DIV/0!
 |  |  |  |  | 0 | #DIV/0! | #DIV/0! | 0.00E+00 | 0.00E+00 | #NUM! | #NUM! | #DIV/0! | #DIV/0! |  | 0.9585 | 1.00E+00 |  | #DIV/0! | #DIV/0! | #DIV/0!
 |  |  |  |  | 0 | #DIV/0! | #DIV/0! | 0.00E+00 | 0.00E+00 | #NUM! | #NUM! | #DIV/0! | #DIV/0! |  | 0.9585 | 1.00E+00 |  | #DIV/0! | #DIV/0! | #DIV/0!
 |  |  |  |  | 0 | #DIV/0! | #DIV/0! | 0.00E+00 | 0.00E+00 | #NUM! | #NUM! | #DIV/0! | #DIV/0! |  | 0.9585 | 1.00E+00 |  | #DIV/0! | #DIV/0! | #DIV/0!
 |  |  |  |  | 0 | #DIV/0! | #DIV/0! | 0.00E+00 | 0.00E+00 | #NUM! | #NUM! | #DIV/0! | #DIV/0! |  | 0.9585 | 1.00E+00 |  | #DIV/0! | #DIV/0! | #DIV/0!
 |  |  |  |  | 0 | #DIV/0! | #DIV/0! | 0.00E+00 | 0.00E+00 | #NUM! | #NUM! | #DIV/0! | #DIV/0! |  | 0.9585 | 1.00E+00 |  | #DIV/0! | #DIV/0! | #DIV/0!
 |  |  |  |  | 0 | #DIV/0! | #DIV/0! | 0.00E+00 | 0.00E+00 | #NUM! | #NUM! | #DIV/0! | #DIV/0! |  | 0.9585 | 1.00E+00 |  | #DIV/0! | #DIV/0! | #DIV/0!
 |  |  |  |  | 0 | #DIV/0! | #DIV/0! | 0.00E+00 | 0.00E+00 | #NUM! | #NUM! | #DIV/0! | #DIV/0! |  | 0.9585 | 1.00E+00 |  | #DIV/0! | #DIV/0! | #DIV/0!
 |  |  |  |  | 0 | #DIV/0! | #DIV/0! | 0.00E+00 | 0.00E+00 | #NUM! | #NUM! | #DIV/0! | #DIV/0! |  | 0.9585 | 1.00E+00 |  | #DIV/0! | #DIV/0! | #DIV/0!
 |  |  |  |  | 0 | #DIV/0! | #DIV/0! | 0.00E+00 | 0.00E+00 | #NUM! | #NUM! | #DIV/0! | #DIV/0! |  | 0.9585 | 1.00E+00 |  | #DIV/0! | #DIV/0! | #DIV/0!
 |  |  |  |  | 0 | #DIV/0! | #DIV/0! | 0.00E+00 | 0.00E+00 | #NUM! | #NUM! | #DIV/0! | #DIV/0! |  | 0.9585 | 1.00E+00 |  | #DIV/0! | #DIV/0! | #DIV/0!
 |  |  |  |  | 0 | #DIV/0! | #DIV/0! | 0.00E+00 | 0.00E+00 | #NUM! | #NUM! | #DIV/0! | #DIV/0! |  | 0.9585 | 1.00E+00 |  | #DIV/0! | #DIV/0! | #DIV/0!
 |  |  |  |  | 0 | #DIV/0! | #DIV/0! | 0.00E+00 | 0.00E+00 | #NUM! | #NUM! | #DIV/0! | #DIV/0! |  | 0.9585 | 1.00E+00 |  | #DIV/0! | #DIV/0! | #DIV/0!
 |  |  |  |  | 0 | #DIV/0! | #DIV/0! | 0.00E+00 | 0.00E+00 | #NUM! | #NUM! | #DIV/0! | #DIV/0! |  | 0.9585 | 1.00E+00 |  | #DIV/0! | #DIV/0! | #DIV/0!
 |  |  |  |  | 0 | #DIV/0! | #DIV/0! | 0.00E+00 | 0.00E+00 | #NUM! | #NUM! | #DIV/0! | #DIV/0! |  | 0.9585 | 1.00E+00 |  | #DIV/0! | #DIV/0! | #DIV/0!
 |  |  |  |  | 0 | #DIV/0! | #DIV/0! | 0.00E+00 | 0.00E+00 | #NUM! | #NUM! | #DIV/0! | #DIV/0! |  | 0.9585 | 1.00E+00 |  | #DIV/0! | #DIV/0! | #DIV/0!
 |  |  |  |  | 0 | #DIV/0! | #DIV/0! | 0.00E+00 | 0.00E+00 | #NUM! | #NUM! | #DIV/0! | #DIV/0! |  | 0.9585 | 1.00E+00 |  | #DIV/0! | #DIV/0! | #DIV/0!
 |  |  |  |  | 0 | #DIV/0! | #DIV/0! | 0.00E+00 | 0.00E+00 | #NUM! | #NUM! | #DIV/0! | #DIV/0! |  | 0.9585 | 1.00E+00 |  | #DIV/0! | #DIV/0! | #DIV/0!
 |  |  |  |  | 0 | #DIV/0! | #DIV/0! | 0.00E+00 | 0.00E+00 | #NUM! | #NUM! | #DIV/0! | #DIV/0! |  | 0.9585 | 1.00E+00 |  | #DIV/0! | #DIV/0! | #DIV/0!
 |  |  |  |  | 0 | #DIV/0! | #DIV/0! | 0.00E+00 | 0.00E+00 | #NUM! | #NUM! | #DIV/0! | #DIV/0! |  | 0.9585 | 1.00E+00 |  | #DIV/0! | #DIV/0! | #DIV/0!
 |  |  |  |  | 0 | #DIV/0! | #DIV/0! | 0.00E+00 | 0.00E+00 | #NUM! | #NUM! | #DIV/0! | #DIV/0! |  | 0.9585 | 1.00E+00 |  | #DIV/0! | #DIV/0! | #DIV/0!
 |  |  |  |  | 0 | #DIV/0! | #DIV/0! | 0.00E+00 | 0.00E+00 | #NUM! | #NUM! | #DIV/0! | #DIV/0! |  | 0.9585 | 1.00E+00 |  | #DIV/0! | #DIV/0! | #DIV/0!
 |  |  |  |  | 0 | #DIV/0! | #DIV/0! | 0.00E+00 | 0.00E+00 | #NUM! | #NUM! | #DIV/0! | #DIV/0! |  | 0.9585 | 1.00E+00 |  | #DIV/0! | #DIV/0! | #DIV/0!
 |  |  |  |  |  |  |  |  |  |  |  |  |  |  | 0.9585 | 1.00E+00
 |  |  |  |  |  |  |  |  |  |  |  |  |  |  | 0.9585 | 1.00E+00
 |  |  |  |  |  |  |  |  |  |  |  |  |  |  | 0.9585 | 1.00E+00
 |  |  |  |  |  |  |  |  |  |  |  |  |  |  | 0.9585 | 1.00E+00
 |  |  |  |  |  |  |  |  |  |  |  |  |  |  | 0.9585 | 1.00E+00
 |  |  |  |  |  |  |  |  |  |  |  |  |  |  | 0.9585 | 1.00E+00
 |  |  |  |  |  |  |  |  |  |  |  |  |  |  | 0.9585 | 1.00E+00
 |  |  |  |  |  |  |  |  |  |  |  |  |  |  | 0.9585 | 1.00E+00
 |  |  |  |  |  |  |  |  |  |  |  |  |  |  | 0.9585 | 1.00E+00
 |  |  |  |  |  |  |  |  |  |  |  |  |  |  | 0.9585 | 1.00E+00
 |  |  |  |  |  |  |  |  |  |  |  |  |  |  | 0.9585 | 1.00E+00
 |  |  |  |  |  |  |  |  |  |  |  |  |  |  | 0.9585 | 1.00E+00
 |  |  |  |  |  |  |  |  |  |  |  |  |  |  | 0.9585 | 1.00E+00
 |  |  |  |  |  |  |  |  |  |  |  |  |  |  | 0.9585 | 1.00E+00
 |  |  |  |  |  |  |  |  |  |  |  |  |  |  | 0.9585 | 1.00E+00
 |  |  |  |  |  |  |  |  |  |  |  |  |  |  | 0.9585 | 1.00E+00
 |  |  |  |  |  |  |  |  |  |  |  |  |  |  | 0.9585 | 1.00E+00
 |  |  |  |  |  |  |  |  |  |  |  |  |  |  | 0.9585 | 1.00E+00
 |  |  |  |  |  |  |  |  |  |  |  |  |  |  | 0.9585 | 1.00E+00
 |  |  |  |  |  |  |  |  |  |  |  |  |  |  | 0.9585 | 1.00E+00
 |  |  |  |  |  |  |  |  |  |  |  |  |  |  | 0.9585 | 1.00E+00
 |  |  |  |  |  |  |  |  |  |  |  |  |  |  | 0.9585 | 1.00E+00
 |  |  |  |  |  |  |  |  |  |  |  |  |  |  | 0.9585 | 1.00E+00
 |  |  |  |  |  |  |  |  |  |  |  |  |  |  | 0.9585 | 1.00E+00
 |  |  |  |  |  |  |  |  |  |  |  |  |  |  | 0.9585 | 1.00E+00
 |  |  |  |  |  |  |  |  |  |  |  |  |  |  | 0.9585 | 1.00E+00
 |  |  |  |  |  |  |  |  |  |  |  |  |  |  | 0.9585 | 1.00E+00
 |  |  |  |  |  |  |  |  |  |  |  |  |  |  | 0.9585 | 1.00E+00
 |  |  |  |  |  |  |  |  |  |  |  |  |  |  | 0.9585 | 1.00E+00
 |  |  |  |  |  |  |  |  |  |  |  |  |  |  | 0.9585 | 1.00E+00
 |  |  |  |  |  |  |  |  |  |  |  |  |  |  | 0.9585 | 1.00E+00
 |  |  |  |  |  |  |  |  |  |  |  |  |  |  | 0.9585 | 1.00E+00
 |  |  |  |  |  |  |  |  |  |  |  |  |  |  | 0.9585 | 1.00E+00
 |  |  |  |  |  |  |  |  |  |  |  |  |  |  | 0.9585 | 1.00E+00
 |  |  |  |  |  |  |  |  |  |  |  |  |  |  | 0.9585 | 1.00E+00
 |  |  |  |  |  |  |  |  |  |  |  |  |  |  | 0.9585 | 1.00E+00
 |  |  |  |  |  |  |  |  |  |  |  |  |  |  | 0.9585 | 1.00E+00
 |  |  |  |  |  |  |  |  |  |  |  |  |  |  | 0.9585 | 1.00E+00
 |  |  |  |  |  |  |  |  |  |  |  |  |  |  | 0.9585 | 1.00E+00
 |  |  |  |  |  |  |  |  |  |  |  |  |  |  | 0.9585 | 1.00E+00
 |  |  |  |  |  |  |  |  |  |  |  |  |  |  | 0.9585 | 1.00E+00
 |  |  |  |  |  |  |  |  |  |  |  |  |  |  | 0.9585 | 1.00E+00
 |  |  |  |  |  |  |  |  |  |  |  |  |  |  | 0.9585 | 1.00E+00
 |  |  |  |  |  |  |  |  |  |  |  |  |  |  | 0.9585 | 1.00E+00
 |  |  |  |  |  |  |  |  |  |  |  |  |  |  | 0.9585 | 1.00E+00
 |  |  |  |  |  |  |  |  |  |  |  |  |  |  | 0.9585 | 1.00E+00
 |  |  |  |  |  |  |  |  |  |  |  |  |  |  | 0.9585 | 1.00E+00
 |  |  |  |  |  |  |  |  |  |  |  |  |  |  | 0.9585 | 1.00E+00
 |  |  |  |  |  |  |  |  |  |  |  |  |  |  | 0.9585 | 1.00E+00
 |  |  |  |  |  |  |  |  |  |  |  |  |  |  | 0.9585 | 1.00E+00
 |  |  |  |  |  |  |  |  |  |  |  |  |  |  | 0.9585 | 1.00E+00
 |  |  |  |  |  |  |  |  |  |  |  |  |  |  | 0.9585 | 1.00E+00
 |  |  |  |  |  |  |  |  |  |  |  |  |  |  | 0.9585 | 1.00E+00
 |  |  |  |  |  |  |  |  |  |  |  |  |  |  | 0.9585 | 1.00E+00
 |  |  |  |  |  |  |  |  |  |  |  |  |  |  | 0.9585 | 1.00E+00
 |  |  |  |  |  |  |  |  |  |  |  |  |  |  | 0.9585 | 1.00E+00
 |  |  |  |  |  |  |  |  |  |  |  |  |  |  | 0.9585 | 1.00E+00
 |  |  |  |  |  |  |  |  |  |  |  |  |  |  | 0.9585 | 1.00E+00
 |  |  |  |  |  |  |  |  |  |  |  |  |  |  | 0.9585 | 1.00E+00
 |  |  |  |  |  |  |  |  |  |  |  |  |  |  | 0.9585 | 1.00E+00
 |  |  |  |  |  |  |  |  |  |  |  |  |  |  | 0.9585 | 1.00E+00
 |  |  |  |  |  |  |  |  |  |  |  |  |  |  | 0.9585 | 1.00E+00
 |  |  |  |  |  |  |  |  |  |  |  |  |  |  | 0.9585 | 1.00E+00
 |  |  |  |  |  |  |  |  |  |  |  |  |  |  | 0.9585 | 1.00E+00
 |  |  |  |  |  |  |  |  |  |  |  |  |  |  | 0.9585 | 1.00E+00
 |  |  |  |  |  |  |  |  |  |  |  |  |  |  | 0.9585 | 1.00E+00
 |  |  |  |  |  |  |  |  |  |  |  |  |  |  | 0.9585 | 1.00E+00
 |  |  |  |  |  |  |  |  |  |  |  |  |  |  | 0.9585 | 1.00E+00
 |  |  |  |  |  |  |  |  |  |  |  |  |  |  | 0.9585 | 1.00E+00
 |  |  |  |  |  |  |  |  |  |  |  |  |  |  | 0.9585 | 1.00E+00
 |  |  |  |  |  |  |  |  |  |  |  |  |  |  | 0.9585 | 1.00E+00
 |  |  |  |  |  |  |  |  |  |  |  |  |  |  | 0.9585 | 1.00E+00
 |  |  |  |  |  |  |  |  |  |  |  |  |  |  | 0.9585 | 1.00E+00
 |  |  |  |  |  |  |  |  |  |  |  |  |  |  | 0.9585 | 1.00E+00
 |  |  |  |  |  |  |  |  |  |  |  |  |  |  | 0.9585 | 1.00E+00
 |  |  |  |  |  |  |  |  |  |  |  |  |  |  | 0.9585 | 1.00E+00
 |  |  |  |  |  |  |  |  |  |  |  |  |  |  | 0.9585 | 1.00E+00
 |  |  |  |  |  |  |  |  |  |  |  |  |  |  | 0.9585 | 1.00E+00
 |  |  |  |  |  |  |  |  |  |  |  |  |  |  | 0.9585 | 1.00E+00
 |  |  |  |  |  |  |  |  |  |  |  |  |  |  | 0.9585 | 1.00E+00
 |  |  |  |  |  |  |  |  |  |  |  |  |  |  | 0.9585 | 1.00E+00
 |  |  |  |  |  |  |  |  |  |  |  |  |  |  | 0.9585 | 1.00E+00
 |  |  |  |  |  |  |  |  |  |  |  |  |  |  | 0.9585 | 1.00E+00
 |  |  |  |  |  |  |  |  |  |  |  |  |  |  | 0.9585 | 1.00E+00
 |  |  |  |  |  |  |  |  |  |  |  |  |  |  | 0.9585 | 1.00E+00
 |  |  |  |  |  |  |  |  |  |  |  |  |  |  |  | 1.00E+00
 |  |  |  |  |  |  |  |  |  |  |  |  |  |  |  | 1.00E+00
 |  |  |  |  |  |  |  |  |  |  |  |  |  |  |  | 1.00E+00
 |  |  |  |  |  |  |  |  |  |  |  |  |  |  |  | 1.00E+00
 |  |  |  |  |  |  |  |  |  |  |  |  |  |  |  | 1.00E+00
 |  |  |  |  |  |  |  |  |  |  |  |  |  |  |  | 1.00E+00
 |  |  |  |  |  |  |  |  |  |  |  |  |  |  |  | 1.00E+00
 |  |  |  |  |  |  |  |  |  |  |  |  |  |  |  | 1.00E+00
 |  |  |  |  |  |  |  |  |  |  |  |  |  |  |  | 1.00E+00
 |  |  |  |  |  |  |  |  |  |  |  |  |  |  |  | 1.00E+00
 |  |  |  |  |  |  |  |  |  |  |  |  |  |  |  | 1.00E+00
 |  |  |  |  |  |  |  |  |  |  |  |  |  |  |  | 1.00E+00
 |  |  |  |  |  |  |  |  |  |  |  |  |  |  |  | 1.00E+00
 |  |  |  |  |  |  |  |  |  |  |  |  |  |  |  | 1.00E+00
 |  |  |  |  |  |  |  |  |  |  |  |  |  |  |  | 1.00E+00
 |  |  |  |  |  |  |  |  |  |  |  |  |  |  |  | 1.00E+00
 |  |  |  |  |  |  |  |  |  |  |  |  |  |  |  | 1.00E+00
 |  |  |  |  |  |  |  |  |  |  |  |  |  |  |  | 1.00E+00
 |  |  |  |  |  |  |  |  |  |  |  |  |  |  |  | 1.00E+00
 |  |  |  |  |  |  |  |  |  |  |  |  |  |  |  | 1.00E+00
 |  |  |  |  |  |  |  |  |  |  |  |  |  |  |  | 1.00E+00
 |  |  |  |  |  |  |  |  |  |  |  |  |  |  |  | 1.00E+00
 |  |  |  |  |  |  |  |  |  |  |  |  |  |  |  | 1.00E+00
 |  |  |  |  |  |  |  |  |  |  |  |  |  |  |  | 1.00E+00
 |  |  |  |  |  |  |  |  |  |  |  |  |  |  |  | 1.00E+00
 |  |  |  |  |  |  |  |  |  |  |  |  |  |  |  | 1.00E+00
 |  |  |  |  |  |  |  |  |  |  |  |  |  |  |  | 1.00E+00
 |  |  |  |  |  |  |  |  |  |  |  |  |  |  |  | 1.00E+00
 |  |  |  |  |  |  |  |  |  |  |  |  |  |  |  | 1.00E+00
 |  |  |  |  |  |  |  |  |  |  |  |  |  |  |  | 1.00E+00
 |  |  |  |  |  |  |  |  |  |  |  |  |  |  |  | 1.00E+00
 |  |  |  |  |  |  |  |  |  |  |  |  |  |  |  | 1.00E+00
 |  |  |  |  |  |  |  |  |  |  |  |  |  |  |  | 1.00E+00
 |  |  |  |  |  |  |  |  |  |  |  |  |  |  |  | 1.00E+00
 |  |  |  |  |  |  |  |  |  |  |  |  |  |  |  | 1.00E+00
 |  |  |  |  |  |  |  |  |  |  |  |  |  |  |  | 1.00E+00
 |  |  |  |  |  |  |  |  |  |  |  |  |  |  |  | 1.00E+00
 |  |  |  |  |  |  |  |  |  |  |  |  |  |  |  | 1.00E+00
 |  |  |  |  | 0 | #DIV/0! | #VALUE! | 0.00E+00 | 0.00E+00 | #NUM! | #NUM! | #VALUE! | #VALUE! |  | 0.9585 | 1.00E+00 |  | #VALUE! | #VALUE! | #VALUE!
 |  |  |  |  | 0 | #DIV/0! | #VALUE! | 0.00E+00 | 0.00E+00 | #NUM! | #NUM! | #VALUE! | #VALUE! |  | 0.9585 | 1.00E+00 |  | #VALUE! | #VALUE! | #VALUE!
 |  |  |  |  | 0 | #DIV/0! | #VALUE! | 0.00E+00 | 0.00E+00 | #NUM! | #NUM! | #VALUE! | #VALUE! |  | 0.9585 | 1.00E+00 |  | #VALUE! | #VALUE! | #VALUE!
 |  |  |  |  | 0 | #DIV/0! | #VALUE! | 0.00E+00 | 0.00E+00 | #NUM! | #NUM! | #VALUE! | #VALUE! |  | 0.9585 | 1.00E+00 |  | #VALUE! | #VALUE! | #VALUE!
 |  |  |  |  | 0 | #DIV/0! | #VALUE! | 0.00E+00 | 0.00E+00 | #NUM! | #NUM! | #VALUE! | #VALUE! |  | 0.9585 | 1.00E+00 |  | #VALUE! | #VALUE! | #VALUE!
 |  |  |  |  | 0 | #DIV/0! | #VALUE! | 0.00E+00 | 0.00E+00 | #NUM! | #NUM! | #VALUE! | #VALUE! |  | 0.9585 | 1.00E+00 |  | #VALUE! | #VALUE! | #VALUE!
 |  |  |  |  | 0 | #DIV/0! | #VALUE! | 0.00E+00 | 0.00E+00 | #NUM! | #NUM! | #VALUE! | #VALUE! |  | 0.9585 | 1.00E+00 |  | #VALUE! | #VALUE! | #VALUE!
 |  |  |  |  | 0 | #DIV/0! | #VALUE! | 0.00E+00 | 0.00E+00 | #NUM! | #NUM! | #VALUE! | #VALUE! |  | 0.9585 | 1.00E+00 |  | #VALUE! | #VALUE! | #VALUE!
 |  |  |  |  | 0 | #DIV/0! | #VALUE! | 0.00E+00 | 0.00E+00 | #NUM! | #NUM! | #VALUE! | #VALUE! |  | 0.9585 | 1.00E+00 |  | #VALUE! | #VALUE! | #VALUE!
 |  |  |  |  | 0 | #DIV/0! | #VALUE! | 0.00E+00 | 0.00E+00 | #NUM! | #NUM! | #VALUE! | #VALUE! |  | 0.9585 | 1.00E+00 |  | #VALUE! | #VALUE! | #VALUE!
 |  |  |  |  | 0 | #DIV/0! | #VALUE! | 0.00E+00 | 0.00E+00 | #NUM! | #NUM! | #VALUE! | #VALUE! |  | 0.9585 | 1.00E+00 |  | #VALUE! | #VALUE! | #VALUE!
 |  |  |  |  | 0 | #DIV/0! | #VALUE! | 0.00E+00 | 0.00E+00 | #NUM! | #NUM! | #VALUE! | #VALUE! |  | 0.9585 | 1.00E+00 |  | #VALUE! | #VALUE! | #VALUE!
 |  |  |  |  | 0 | #DIV/0! | #VALUE! | 0.00E+00 | 0.00E+00 | #NUM! | #NUM! | #VALUE! | #VALUE! |  | 0.9585 | 1.00E+00 |  | #VALUE! | #VALUE! | #VALUE!
 |  |  |  |  | 0 | #DIV/0! | #VALUE! | 0.00E+00 | 0.00E+00 | #NUM! | #NUM! | #VALUE! | #VALUE! |  | 0.9585 | 1.00E+00 |  | #VALUE! | #VALUE! | #VALUE!
 |  |  |  |  | 0 | #DIV/0! | #VALUE! | 0.00E+00 | 0.00E+00 | #NUM! | #NUM! | #VALUE! | #VALUE! |  | 0.9585 | 1.00E+00 |  | #VALUE! | #VALUE! | #VALUE!
 |  |  |  |  | 0 | #DIV/0! | #VALUE! | 0.00E+00 | 0.00E+00 | #NUM! | #NUM! | #VALUE! | #VALUE! |  | 0.9585 | 1.00E+00 |  | #VALUE! | #VALUE! | #VALUE!
 |  |  |  |  | 0 | #DIV/0! | #VALUE! | 0.00E+00 | 0.00E+00 | #NUM! | #NUM! | #VALUE! | #VALUE! |  | 0.9585 | 1.00E+00 |  | #VALUE! | #VALUE! | #VALUE!
 |  |  |  |  | 0 | #DIV/0! | #VALUE! | 0.00E+00 | 0.00E+00 | #NUM! | #NUM! | #VALUE! | #VALUE! |  | 0.9585 | 1.00E+00 |  | #VALUE! | #VALUE! | #VALUE!
 |  |  |  |  | 0 | #DIV/0! | #VALUE! | 0.00E+00 | 0.00E+00 | #NUM! | #NUM! | #VALUE! | #VALUE! |  | 0.9585 | 1.00E+00 |  | #VALUE! | #VALUE! | #VALUE!
 |  |  |  |  | 0 | #DIV/0! | #VALUE! | 0.00E+00 | 0.00E+00 | #NUM! | #NUM! | #VALUE! | #VALUE! |  | 0.9585 | 1.00E+00 |  | #VALUE! | #VALUE! | #VALUE!
 |  |  |  |  | 0 | #DIV/0! | #VALUE! | 0.00E+00 | 0.00E+00 | #NUM! | #NUM! | #VALUE! | #VALUE! |  | 0.9585 | 1.00E+00 |  | #VALUE! | #VALUE! | #VALUE!
 |  |  |  |  | 0 | #DIV/0! | #VALUE! | 0.00E+00 | 0.00E+00 | #NUM! | #NUM! | #VALUE! | #VALUE! |  | 0.9585 | 1.00E+00 |  | #VALUE! | #VALUE! | #VALUE!
 |  |  |  |  | 0 | #DIV/0! | #VALUE! | 0.00E+00 | 0.00E+00 | #NUM! | #NUM! | #VALUE! | #VALUE! |  | 0.9585 | 1.00E+00 |  | #VALUE! | #VALUE! | #VALUE!
 |  |  |  |  | 0 | #DIV/0! | #VALUE! | 0.00E+00 | 0.00E+00 | #NUM! | #NUM! | #VALUE! | #VALUE! |  | 0.9585 | 1.00E+00 |  | #VALUE! | #VALUE! | #VALUE!
 |  |  |  |  | 0 | #DIV/0! | #VALUE! | 0.00E+00 | 0.00E+00 | #NUM! | #NUM! | #VALUE! | #VALUE! |  | 0.9585 | 1.00E+00 |  | #VALUE! | #VALUE! | #VALUE!
 |  |  |  |  | 0 | #DIV/0! | #VALUE! | 0.00E+00 | 0.00E+00 | #NUM! | #NUM! | #VALUE! | #VALUE! |  | 0.9585 | 1.00E+00 |  | #VALUE! | #VALUE! | #VALUE!
 |  |  |  |  | 0 | #DIV/0! | #VALUE! | 0.00E+00 | 0.00E+00 | #NUM! | #NUM! | #VALUE! | #VALUE! |  | 0.9585 | 1.00E+00 |  | #VALUE! | #VALUE! | #VALUE!
 |  |  |  |  | 0 | #DIV/0! | #VALUE! | 0.00E+00 | 0.00E+00 | #NUM! | #NUM! | #VALUE! | #VALUE! |  | 0.9585 | 1.00E+00 |  | #VALUE! | #VALUE! | #VALUE!
 |  |  |  |  | 0 | #DIV/0! | #VALUE! | 0.00E+00 | 0.00E+00 | #NUM! | #NUM! | #VALUE! | #VALUE! |  | 0.9585 | 1.00E+00 |  | #VALUE! | #VALUE! | #VALUE!
 |  |  |  |  | 0 | #DIV/0! | #VALUE! | 0.00E+00 | 0.00E+00 | #NUM! | #NUM! | #VALUE! | #VALUE! |  | 0.9585 | 1.00E+00 |  | #VALUE! | #VALUE! | #VALUE!
 |  |  |  |  | 0 | #DIV/0! | #VALUE! | 0.00E+00 | 0.00E+00 | #NUM! | #NUM! | #VALUE! | #VALUE! |  | 0.9585 | 1.00E+00 |  | #VALUE! | #VALUE! | #VALUE!
 |  |  |  |  | 0 | #DIV/0! | #VALUE! | 0.00E+00 | 0.00E+00 | #NUM! | #NUM! | #VALUE! | #VALUE! |  | 0.9585 | 1.00E+00 |  | #VALUE! | #VALUE! | #VALUE!
 |  |  |  |  | 0 | #DIV/0! | #VALUE! | 0.00E+00 | 0.00E+00 | #NUM! | #NUM! | #VALUE! | #VALUE! |  | 0.9585 | 1.00E+00 |  | #VALUE! | #VALUE! | #VALUE!
 |  |  |  |  | 0 | #DIV/0! | #VALUE! | 0.00E+00 | 0.00E+00 | #NUM! | #NUM! | #VALUE! | #VALUE! |  | 0.9585 | 1.00E+00 |  | #VALUE! | #VALUE! | #VALUE!
 |  |  |  |  | 0 | #DIV/0! | #VALUE! | 0.00E+00 | 0.00E+00 | #NUM! | #NUM! | #VALUE! | #VALUE! |  | 0.9585 | 1.00E+00 |  | #VALUE! | #VALUE! | #VALUE!
 |  |  |  |  | 0 | #DIV/0! | #VALUE! | 0.00E+00 | 0.00E+00 | #NUM! | #NUM! | #VALUE! | #VALUE! |  | 0.9585 | 1.00E+00 |  | #VALUE! | #VALUE! | #VALUE!
 |  |  |  |  | 0 | #DIV/0! | #VALUE! | 0.00E+00 | 0.00E+00 | #NUM! | #NUM! | #VALUE! | #VALUE! |  | 0.9585 | 1.00E+00 |  | #VALUE! | #VALUE! | #VALUE!
 |  |  |  |  | 0 | #DIV/0! | #VALUE! | 0.00E+00 | 0.00E+00 | #NUM! | #NUM! | #VALUE! | #VALUE! |  | 0.9585 | 1.00E+00 |  | #VALUE! | #VALUE! | #VALUE!
 |  |  |  |  | 0 | #DIV/0! | #VALUE! | 0.00E+00 | 0.00E+00 | #NUM! | #NUM! | #VALUE! | #VALUE! |  | 0.9585 | 1.00E+00 |  | #VALUE! | #VALUE! | #VALUE!
 |  |  |  |  | 0 | #DIV/0! | #VALUE! | 0.00E+00 | 0.00E+00 | #NUM! | #NUM! | #VALUE! | #VALUE! |  | 0.9585 | 1.00E+00 |  | #VALUE! | #VALUE! | #VALUE!
 |  |  |  |  | 0 | #DIV/0! | #VALUE! | 0.00E+00 | 0.00E+00 | #NUM! | #NUM! | #VALUE! | #VALUE! |  | 0.9585 | 1.00E+00 |  | #VALUE! | #VALUE! | #VALUE!
 |  |  |  |  | 0 | #DIV/0! | #VALUE! | 0.00E+00 | 0.00E+00 | #NUM! | #NUM! | #VALUE! | #VALUE! |  | 0.9585 | 1.00E+00 |  | #VALUE! | #VALUE! | #VALUE!
 |  |  |  |  | 0 | #DIV/0! | #VALUE! | 0.00E+00 | 0.00E+00 | #NUM! | #NUM! | #VALUE! | #VALUE! |  | 0.9585 | 1.00E+00 |  | #VALUE! | #VALUE! | #VALUE!
 |  |  |  |  | 0 | #DIV/0! | #VALUE! | 0.00E+00 | 0.00E+00 | #NUM! | #NUM! | #VALUE! | #VALUE! |  | 0.9585 | 1.00E+00 |  | #VALUE! | #VALUE! | #VALUE!
 |  |  |  |  | 0 | #DIV/0! | #VALUE! | 0.00E+00 | 0.00E+00 | #NUM! | #NUM! | #VALUE! | #VALUE! |  | 0.9585 | 1.00E+00 |  | #VALUE! | #VALUE! | #VALUE!
 |  |  |  |  | 0 | #DIV/0! | #VALUE! | 0.00E+00 | 0.00E+00 | #NUM! | #NUM! | #VALUE! | #VALUE! |  | 0.9585 | 1.00E+00 |  | #VALUE! | #VALUE! | #VALUE!
 |  |  |  |  | 0 | #DIV/0! | #VALUE! | 0.00E+00 | 0.00E+00 | #NUM! | #NUM! | #VALUE! | #VALUE! |  | 0.9585 | 1.00E+00 |  | #VALUE! | #VALUE! | #VALUE!
 |  |  |  |  | 0 | #DIV/0! | #VALUE! | 0.00E+00 | 0.00E+00 | #NUM! | #NUM! | #VALUE! | #VALUE! |  | 0.9585 | 1.00E+00 |  | #VALUE! | #VALUE! | #VALUE!
 |  |  |  |  | 0 | #DIV/0! | #VALUE! | 0.00E+00 | 0.00E+00 | #NUM! | #NUM! | #VALUE! | #VALUE! |  | 0.9585 | 1.00E+00 |  | #VALUE! | #VALUE! | #VALUE!
 |  |  |  |  | 0 | #DIV/0! | #VALUE! | 0.00E+00 | 0.00E+00 | #NUM! | #NUM! | #VALUE! | #VALUE! |  | 0.9585 | 1.00E+00 |  | #VALUE! | #VALUE! | #VALUE!
 |  |  |  |  | 0 | #DIV/0! | #VALUE! | 0.00E+00 | 0.00E+00 | #NUM! | #NUM! | #VALUE! | #VALUE! |  | 0.9585 | 1.00E+00 |  | #VALUE! | #VALUE! | #VALUE!
 |  |  |  |  | 0 | #DIV/0! | #VALUE! | 0.00E+00 | 0.00E+00 | #NUM! | #NUM! | #VALUE! | #VALUE! |  | 0.9585 | 1.00E+00 |  | #VALUE! | #VALUE! | #VALUE!
 |  |  |  |  | 0 | #DIV/0! | #VALUE! | 0.00E+00 | 0.00E+00 | #NUM! | #NUM! | #VALUE! | #VALUE! |  | 0.9585 | 1.00E+00 |  | #VALUE! | #VALUE! | #VALUE!
 |  |  |  |  | 0 | #DIV/0! | #VALUE! | 0.00E+00 | 0.00E+00 | #NUM! | #NUM! | #VALUE! | #VALUE! |  | 0.9585 | 1.00E+00 |  | #VALUE! | #VALUE! | #VALUE!
 |  |  |  |  | 0 | #DIV/0! | #VALUE! | 0.00E+00 | 0.00E+00 | #NUM! | #NUM! | #VALUE! | #VALUE! |  | 0.9585 | 1.00E+00 |  | #VALUE! | #VALUE! | #VALUE!
 |  |  |  |  | 0 | #DIV/0! | #VALUE! | 0.00E+00 | 0.00E+00 | #NUM! | #NUM! | #VALUE! | #VALUE! |  | 0.9585 | 1.00E+00 |  | #VALUE! | #VALUE! | #VALUE!
 |  |  |  |  | 0 | #DIV/0! | #VALUE! | 0.00E+00 | 0.00E+00 | #NUM! | #NUM! | #VALUE! | #VALUE! |  | 0.9585 | 1.00E+00 |  | #VALUE! | #VALUE! | #VALUE!
 |  |  |  |  | 0 | #DIV/0! | #VALUE! | 0.00E+00 | 0.00E+00 | #NUM! | #NUM! | #VALUE! | #VALUE! |  | 0.9585 | 1.00E+00 |  | #VALUE! | #VALUE! | #VALUE!
 |  |  |  |  | 0 | #DIV/0! | #VALUE! | 0.00E+00 | 0.00E+00 | #NUM! | #NUM! | #VALUE! | #VALUE! |  | 0.9585 | 1.00E+00 |  | #VALUE! | #VALUE! | #VALUE!
 |  |  |  |  | 0 | #DIV/0! | #VALUE! | 0.00E+00 | 0.00E+00 | #NUM! | #NUM! | #VALUE! | #VALUE! |  | 0.9585 | 1.00E+00 |  | #VALUE! | #VALUE! | #VALUE!
 |  |  |  |  | 0 | #DIV/0! | #VALUE! | 0.00E+00 | 0.00E+00 | #NUM! | #NUM! | #VALUE! | #VALUE! |  | 0.9585 | 1.00E+00 |  | #VALUE! | #VALUE! | #VALUE!
 |  |  |  |  | 0 | #DIV/0! | #VALUE! | 0.00E+00 | 0.00E+00 | #NUM! | #NUM! | #VALUE! | #VALUE! |  | 0.9585 | 1.00E+00 |  | #VALUE! | #VALUE! | #VALUE!
 |  |  |  |  | 0 | #DIV/0! | #VALUE! | 0.00E+00 | 0.00E+00 | #NUM! | #NUM! | #VALUE! | #VALUE! |  | 0.9585 | 1.00E+00 |  | #VALUE! | #VALUE! | #VALUE!
 |  |  |  |  | 0 | #DIV/0! | #VALUE! | 0.00E+00 | 0.00E+00 | #NUM! | #NUM! | #VALUE! | #VALUE! |  | 0.9585 | 1.00E+00 |  | #VALUE! | #VALUE! | #VALUE!
 |  |  |  |  | 0 | #DIV/0! | #VALUE! | 0.00E+00 | 0.00E+00 | #NUM! | #NUM! | #VALUE! | #VALUE! |  | 0.9585 | 1.00E+00 |  | #VALUE! | #VALUE! | #VALUE!
 |  |  |  |  | 0 | #DIV/0! | #VALUE! | 0.00E+00 | 0.00E+00 | #NUM! | #NUM! | #VALUE! | #VALUE! |  | 0.9585 | 1.00E+00 |  | #VALUE! | #VALUE! | #VALUE!
 |  |  |  |  | 0 | #DIV/0! | #VALUE! | 0.00E+00 | 0.00E+00 | #NUM! | #NUM! | #VALUE! | #VALUE! |  | 0.9585 | 1.00E+00 |  | #VALUE! | #VALUE! | #VALUE!
 |  |  |  |  | 0 | #DIV/0! | #VALUE! | 0.00E+00 | 0.00E+00 | #NUM! | #NUM! | #VALUE! | #VALUE! |  | 0.9585 | 1.00E+00 |  | #VALUE! | #VALUE! | #VALUE!
 |  |  |  |  | 0 | #DIV/0! | #VALUE! | 0.00E+00 | 0.00E+00 | #NUM! | #NUM! | #VALUE! | #VALUE! |  | 0.9585 | 1.00E+00 |  | #VALUE! | #VALUE! | #VALUE!
 |  |  |  |  | 0 | #DIV/0! | #VALUE! | 0.00E+00 | 0.00E+00 | #NUM! | #NUM! | #VALUE! | #VALUE! |  | 0.9585 | 1.00E+00 |  | #VALUE! | #VALUE! | #VALUE!
 |  |  |  |  | 0 | #DIV/0! | #VALUE! | 0.00E+00 | 0.00E+00 | #NUM! | #NUM! | #VALUE! | #VALUE! |  | 0.9585 | 1.00E+00 |  | #VALUE! | #VALUE! | #VALUE!
 |  |  |  |  | 0 | #DIV/0! | #VALUE! | 0.00E+00 | 0.00E+00 | #NUM! | #NUM! | #VALUE! | #VALUE! |  | 0.9585 | 1.00E+00 |  | #VALUE! | #VALUE! | #VALUE!
 |  |  |  |  | 0 | #DIV/0! | #VALUE! | 0.00E+00 | 0.00E+00 | #NUM! | #NUM! | #VALUE! | #VALUE! |  | 0.9585 | 1.00E+00 |  | #VALUE! | #VALUE! | #VALUE!
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

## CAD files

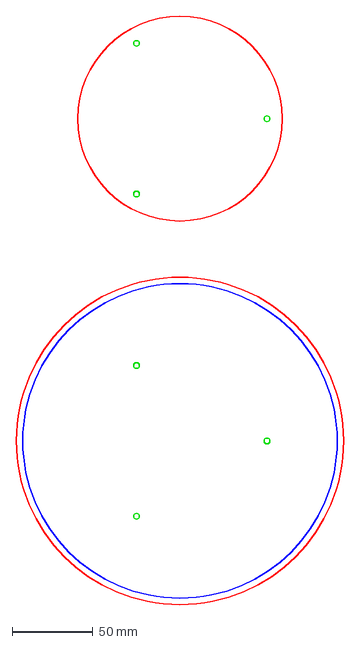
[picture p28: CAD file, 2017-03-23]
housing/Ott_plate_housing_fixed.dxf
203.2 x 365.1 mm

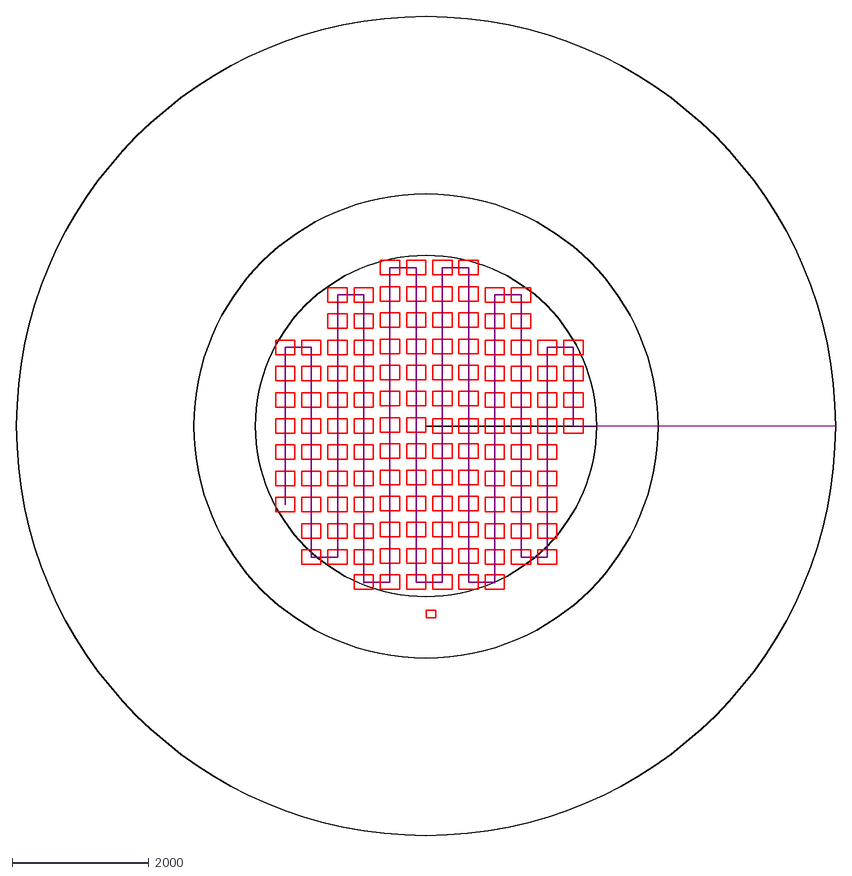
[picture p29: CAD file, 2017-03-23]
microscopy/scanplan4.dxf
12000.0 x 12000.0

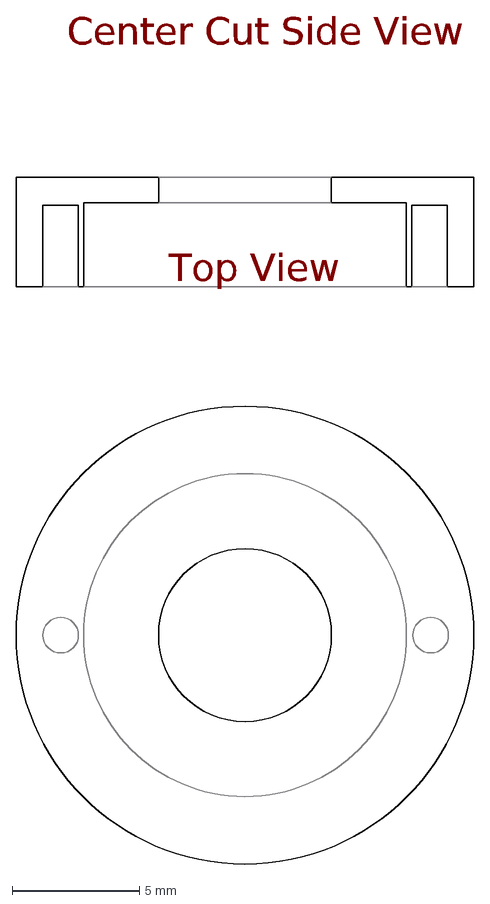
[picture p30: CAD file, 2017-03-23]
monitor/cap-diagram.dxf
Center Cut Side View
Top View

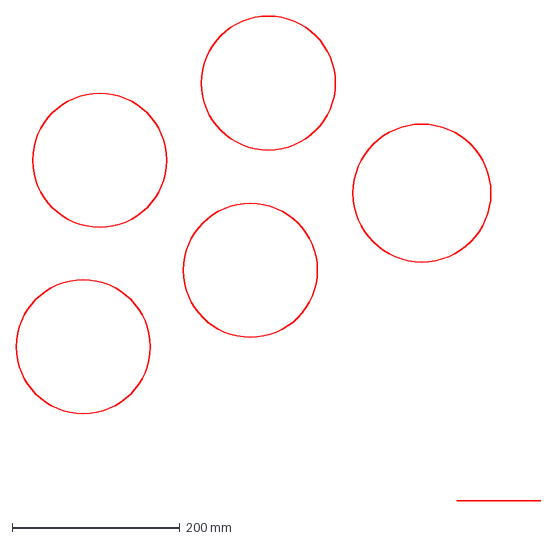
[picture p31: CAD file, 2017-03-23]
monitor/images/MESH-CENTER2CENTER.dxf
626.1 x 578.8 mm

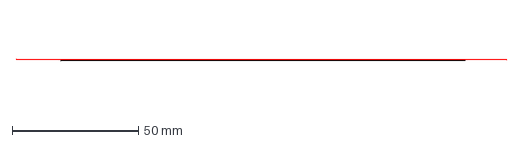
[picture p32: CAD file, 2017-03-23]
monitor/images/mesh-hole-taper.dxf
194.0 x 0.461 mm

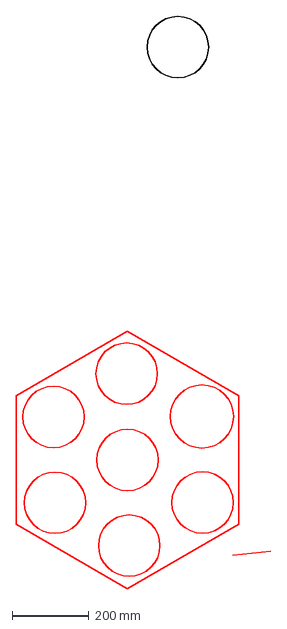
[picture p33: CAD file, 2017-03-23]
monitor/images/mesh-hole-area.dxf
663.6 x 1489.9 mm

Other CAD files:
monitor/~cap-diagram.dxf

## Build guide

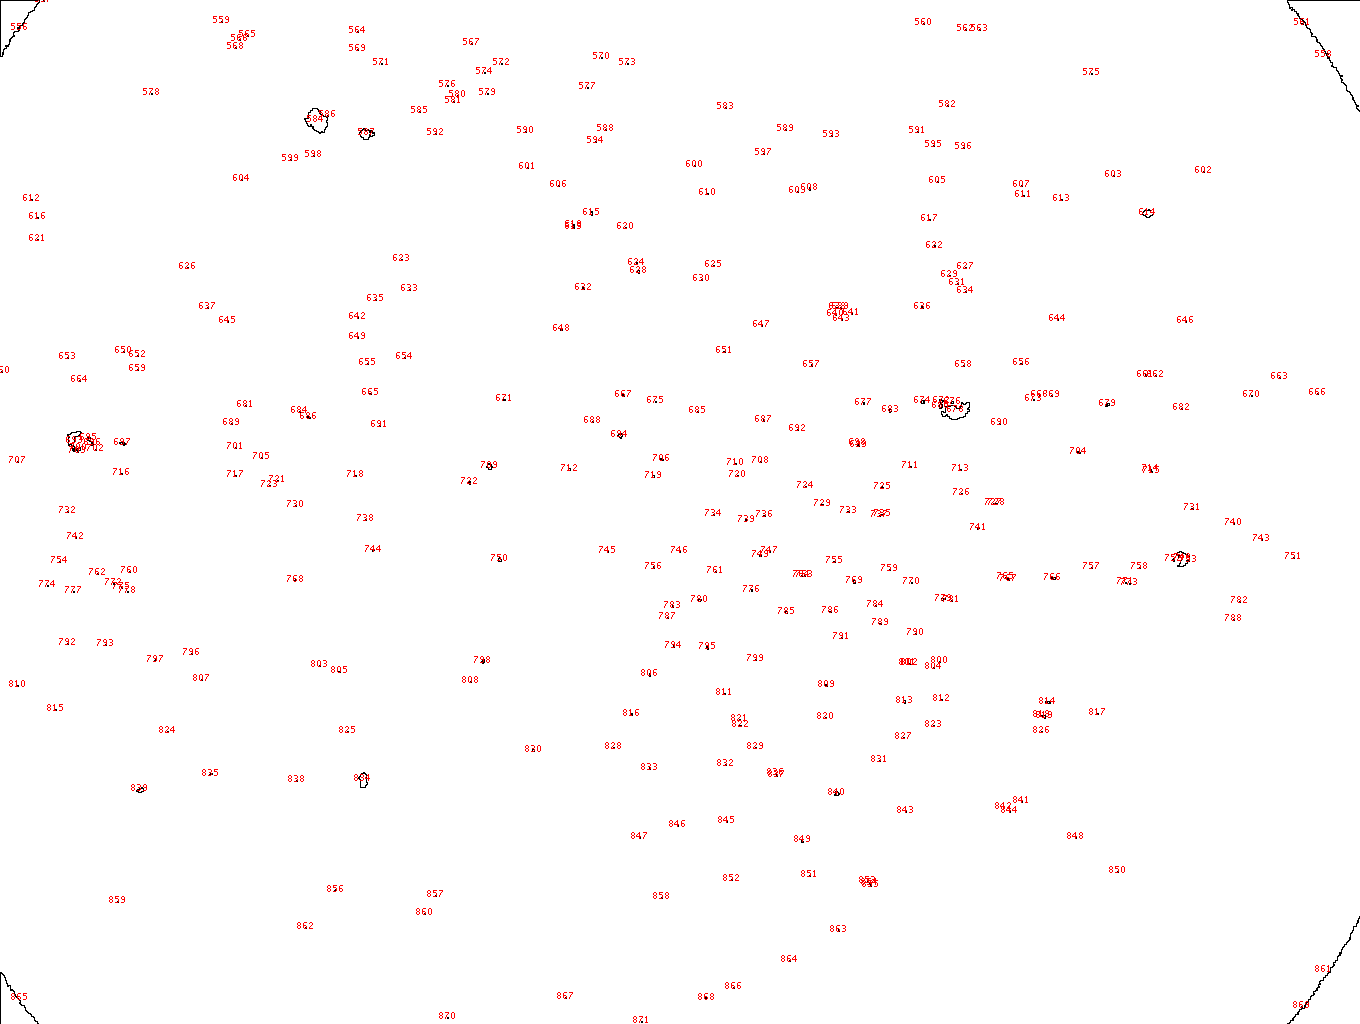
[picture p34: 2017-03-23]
microscopy/images/Wi_HA_113015_20x_3.tif_step7_ParticleCounts.tif

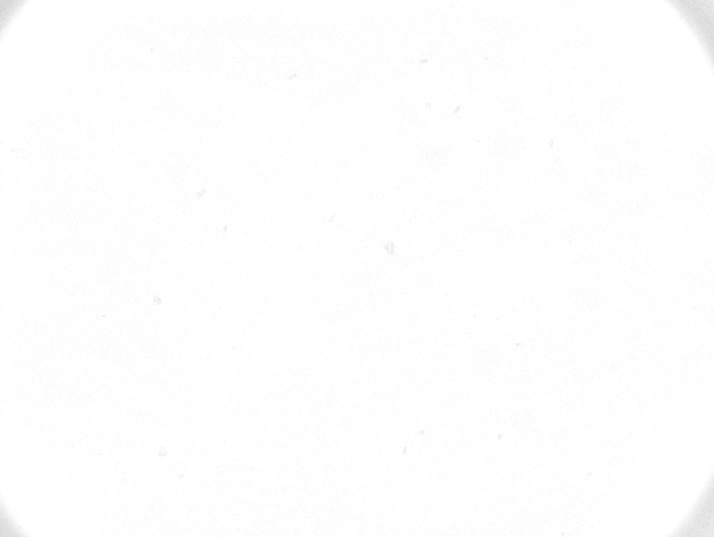
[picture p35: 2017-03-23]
microscopy/images/Wi_HA_113015_40x_3.tif_step1_Pseudo_corrected.tif

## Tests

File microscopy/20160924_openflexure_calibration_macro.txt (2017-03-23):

run("Bandpass Filter...", "filter_large=40 filter_small=3 suppress=None tolerance=5 autoscale saturate");
run("Subtract Background...", "rolling=50 light sliding");
run("8-bit");
setAutoThreshold("Default");
//run("Threshold...");
setAutoThreshold("MaxEntropy");
//setThreshold(0, 231);
setOption("BlackBackground", false);
run("Convert to Mask");
run("Close");
run("Crop");
//setTool("rectangle");
//setTool("rectangle");
makeRectangle(24, 99, 2556, 1827);

run("Crop");
run("Make Binary");
run("Fill Holes");
run("Set Measurements...", "area perimeter shape display redirect=None decimal=3");
run("Analyze Particles...", "size=.5-Infinity show=Outlines display");

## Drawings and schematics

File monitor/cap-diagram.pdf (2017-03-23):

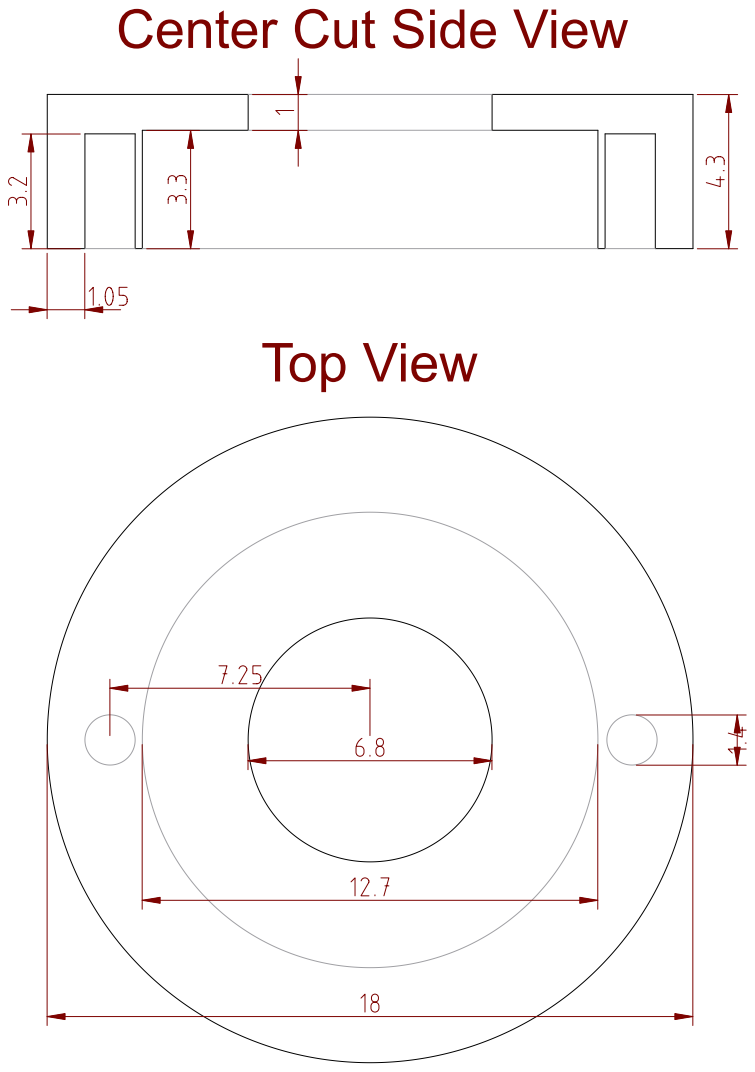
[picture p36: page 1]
Top View

Center Cut Side View
